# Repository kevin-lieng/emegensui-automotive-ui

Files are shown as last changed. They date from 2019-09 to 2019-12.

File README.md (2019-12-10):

# 2019 - 2020 AutomotiveUI (IMU Sensor)
## BerryIMU + ESP8266 Build Instructions

## System Diagram

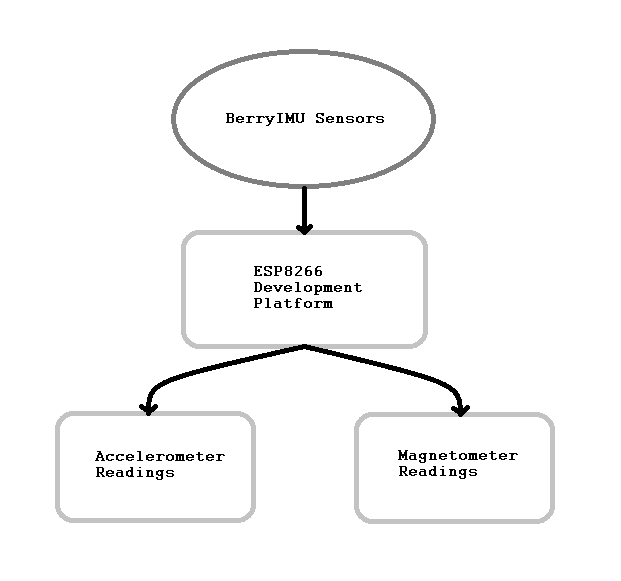
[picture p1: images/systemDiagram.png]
systemDiagram


Using the system diagram above, you can visualize how the BerryIMU interacts with the ESP8266 Development platform to retrieve the readings of the sensors within it. Although there are only two sensors that are being read within the above diagram, there are still several more sensors that can be used to retrieve data. 

## Introduction
--------------------------------------------------------
BerryIMU is a third-party made PCB board that has several sensors that can be used to retrieve data. IMU stands for Inertial Measurement Unit, these are the units that relate to the movement of something. Not only is this third-party sensor capable of reading movement, but it can also read temperature, pressure, and geographical location. However, this documentation will be discussing the 
usage of this sensor to retrieve the data of basic movement and direction. Within this repository, you will find the multiple files that are available to use alongside with the instructions given for public use. These files can aid in the installation of the hardware and the software needed for the basic functionality of retrieving intertial and directional data. 

## Table of Contents 
--------------------------------------------------------
- [System Diagram](#System-Diagram)
- [Introduction](#Introduction)
- [Components Needed (Cost)](#Components-Needed-Cost)
- [Time Commitment](#time-commitment)
- [Mechanical Assembly](#mechanical-assembly)
- [PCB and Soldering](#PCB-and-soldering)
- [Enclosure](#Enclosure)

--------------------------------------------------------

## Components Needed (Cost)
-------------------------------------------------------
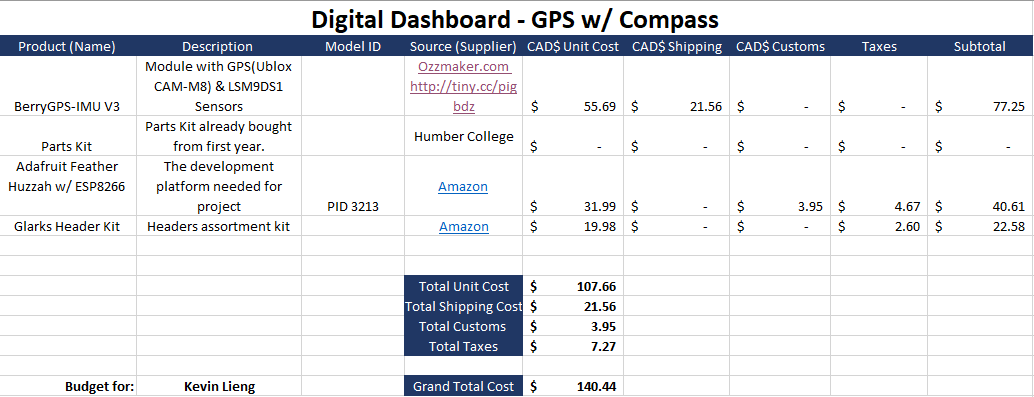
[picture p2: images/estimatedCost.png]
estimatedCost

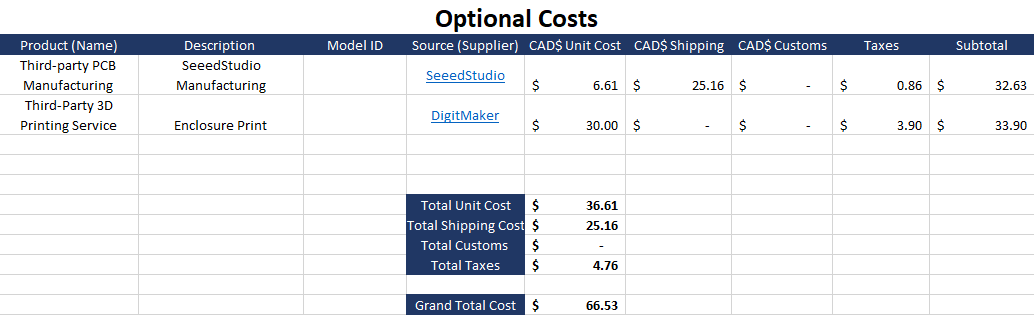
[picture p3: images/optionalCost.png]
optionalCost


The cost of the product depends on what type of services are available to you as a student or individual. If there are services near you that offer fine 3D printing services and fine PCB services at no cost, you may ignore the optional costs of this project. The necessary components of this project are stated within the first image of this section. Due to the main sensor, BerryIMU, being made by a third-party in Australia. The shipping of this component may take longer than the others listed. Most of these components may ship to you at no cost due to the availability of them on Amazon. 

The minimum cost of the project can be $140.44; however, if third-party manufacturing and printing services are needed, the upper cost can be $206.97.

## Time Commitment
-------------------------------------------------------
By using this documentation, a user can potentially finish this project within a day to three days depending on the avaialbility of the components needed within this project. 

On completion of this project, the final product should look like the following pictures below: 

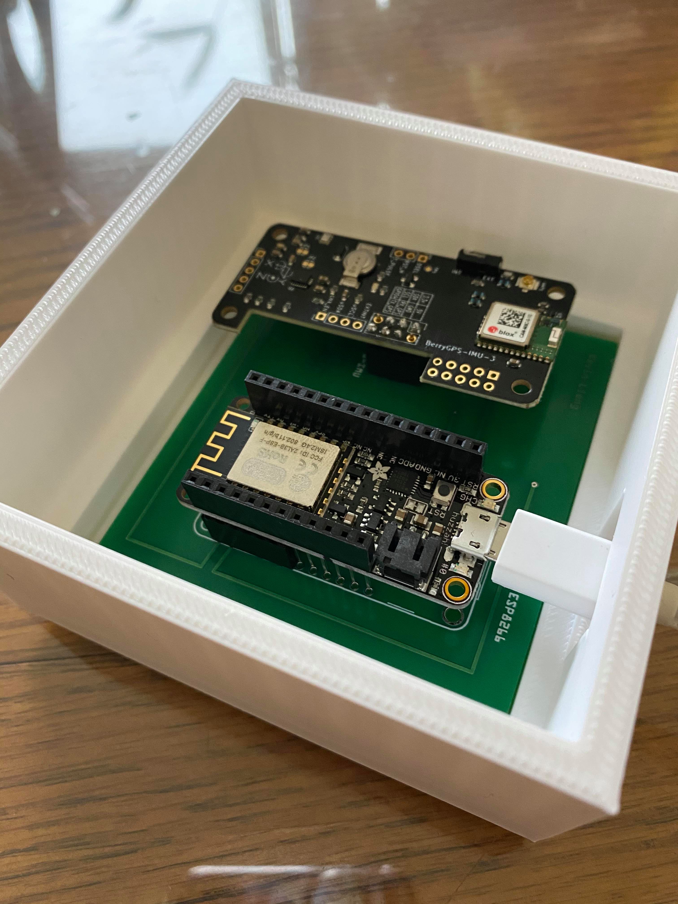
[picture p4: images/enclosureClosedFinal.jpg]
FinishedProduct

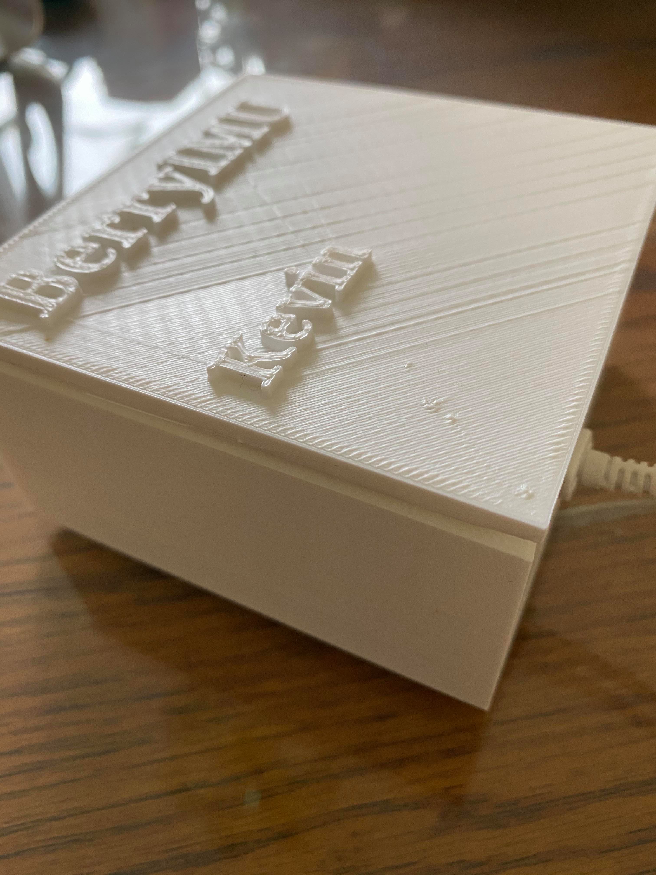
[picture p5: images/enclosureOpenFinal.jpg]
FinishedProductOpen


Although a user using this documentation can develop the project in three days with this documentation. The planning of this project took a span of 3 months to plan out the implementation of the PCB board, enclosure, and multiple testing as seen below. 

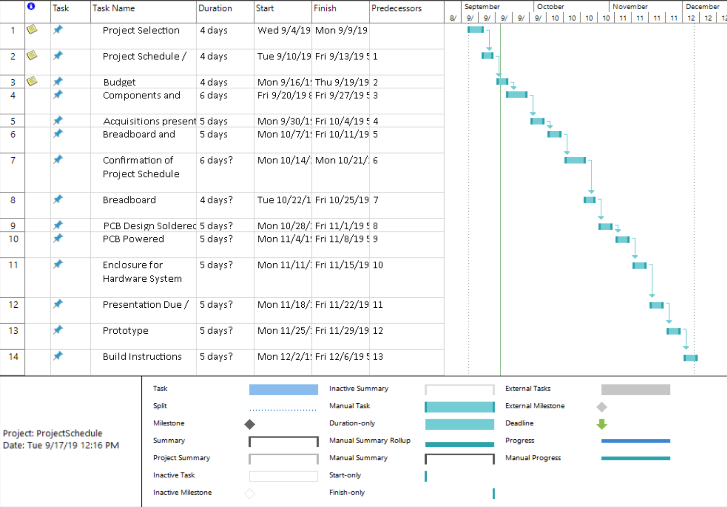
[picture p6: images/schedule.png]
SchedulePDF


This is due to the extra time needed to work out errors that have occured and the switching of development platforms and remaking of PCB board and enclosures to meet the new components needed. The components that are shown as needed in the [budget](#components-needed-cost) portion above have the unnecessary products taken out. If you would like to see the the previous components that were used, the may be found [here](documentation/ProjectBudget.pdf).

## Mechanical Assembly
------------------------------------------------------------
### Step One : Setting up the Adafruit Feather Huzzah ESP8266

Before connecting the sensor to the development platform, ESP8266, you should setup the development platform itself. The development platform should be enabled to be programmed through the Arduino IDE (Integrated Development Environment). 

To start, you would need to [download the Arduino IDE from Arduino.cc](https://www.arduino.cc/en/Main/Software).

Next, you would have to integrate the board drivers of the ESP8266 into the Arduino IDE by copying the following:

    http://arduino.esp8266.com/stable/package_esp8266com_index.json

This link should be copied and pasted into the Additional Boards Manager URL field. This field can be found under **File > Preferences** . The window for this section should look like the following: 

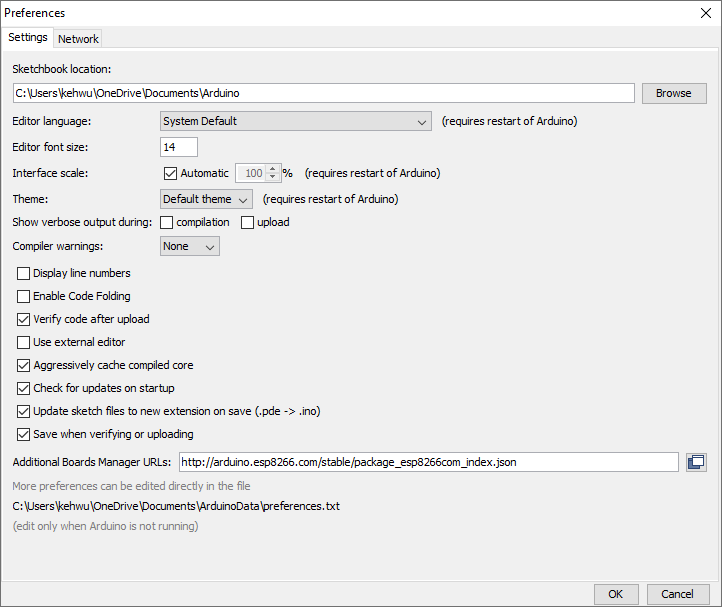
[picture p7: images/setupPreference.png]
preferences


Next, you will have to navigate to the board manager through the top menu using: **Tools > Boards > Board Manager** . You will then have to install the ESP8266 board drivers and made by the Arduino Community. The screen of the board manager will appear as this in Windows: 

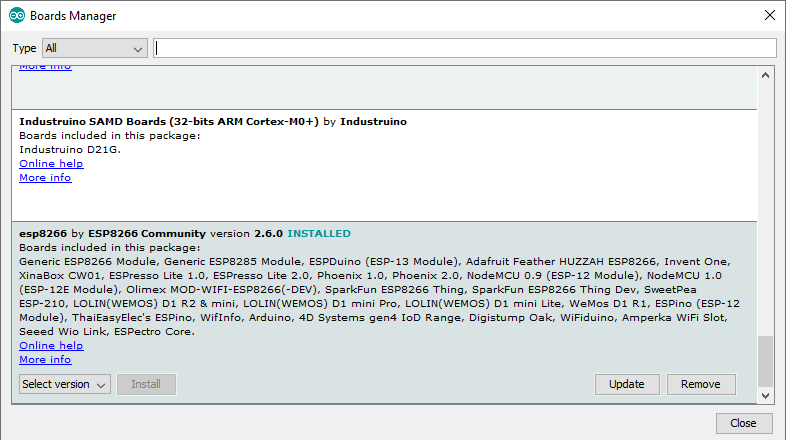
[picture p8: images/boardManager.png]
boardManager


After the installation, you may connect the ESP8266 development platform to your computer / laptop using a MicroUSB to USB cable to a USB Port of your device. After connecting, you will have to select the correct port of your ESP8266 platform. This is done through the top menu using **Tools > Port > COM#**, you will have to select the correct COM port of your device. 

After the sucessful connection of your platform, you will then need to test your platform by running a simple **Blink Test** by using the following code:

    void setup() {
    pinMode(0, OUTPUT);
    }
 
    void loop() {
    digitalWrite(0, HIGH);
    delay(500);
    digitalWrite(0, LOW);
    delay(500);
    }

Upon the successful uploading of this code to your platform, you shall see the LEDs of the ESP8266 to be blinking. 

### Step Two: Connection of the BerryIMU Sensor

The next step would be the connection of the BerryIMU sensor to the development platform itself. The best way to do this would be to first solder male headers to the sensor itself. In the following locations:

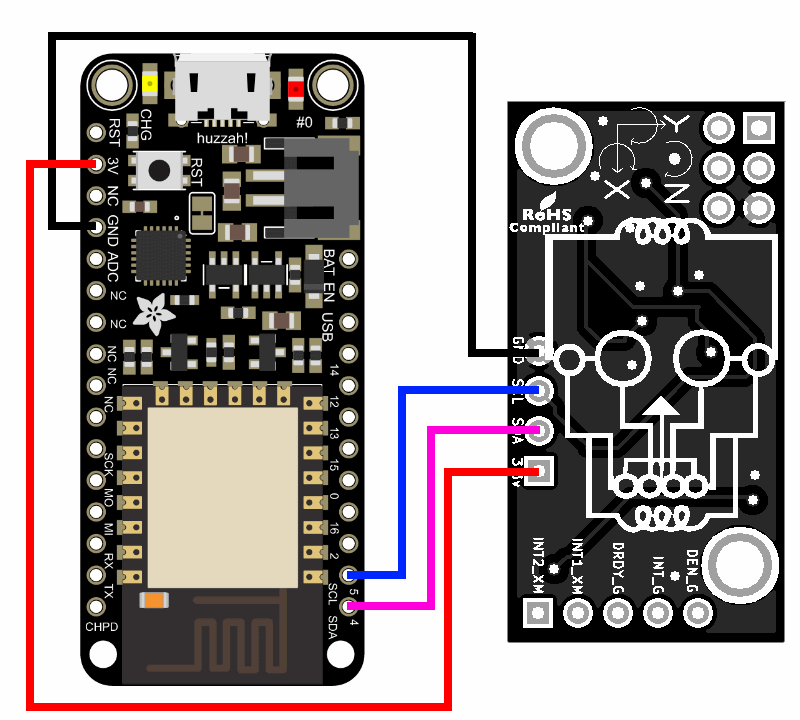
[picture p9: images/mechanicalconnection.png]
mechanicalConnection


After soldering male headers to those pinouts of BerryIMU sensor on the right, you can then use several female to female wires to connect the sensor to the platform like the diagram above. 

## Step Three: Implementing Code For Testing

The next step would be to implement the code for testing the sensors itself and if they're capable of reading gyrometer, magnetometer, and accelerometer data. To do this, you can start a new sketch within the Arduino IDE and have the main file include the code within the BerryIMU.ino file. 

- [BerryIMU.ino File](software/BerryIMU%20Codes/BerryIMU.ino) 

You can then include the following files within the same folder of the main BerryIMU.ino file: 

- [IMU.cpp File](software/BerryIMU%20Codes/IMU.cpp)
- [IMU.h File](software/BerryIMU%20Codes/IMU.h)
- [LSM9DS0.h File](software/BerryIMU%20Codes/LSM9DS0.h)
- [LSM9DS1.h File](software/BerryIMU%20Codes/LSM9DS1.h)

When implemented correctly, your Arduino IDE window should look like the following: 

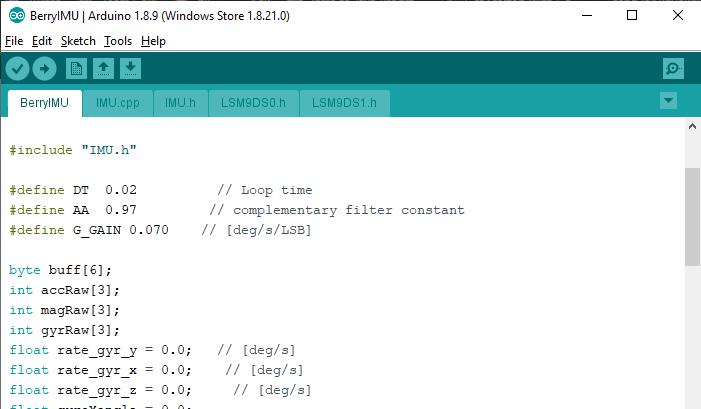
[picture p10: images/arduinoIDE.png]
arduinoIDE


### Step Four: Uploading and Checking Readings

After the implementation, you may now upload the program into the ESP8266 development platform. After the successful upload of the program, you can open the Serial Monitor within the Arduino IDE to see the readings of the sensor. To test for movement, you may move the sensor around and check for movement in the readings. 

The Serial Monitor can be found in the same top menu of Arduino IDE under **Tools > Serial Monitor**. When the correct window is open, the screen will look like the following: 

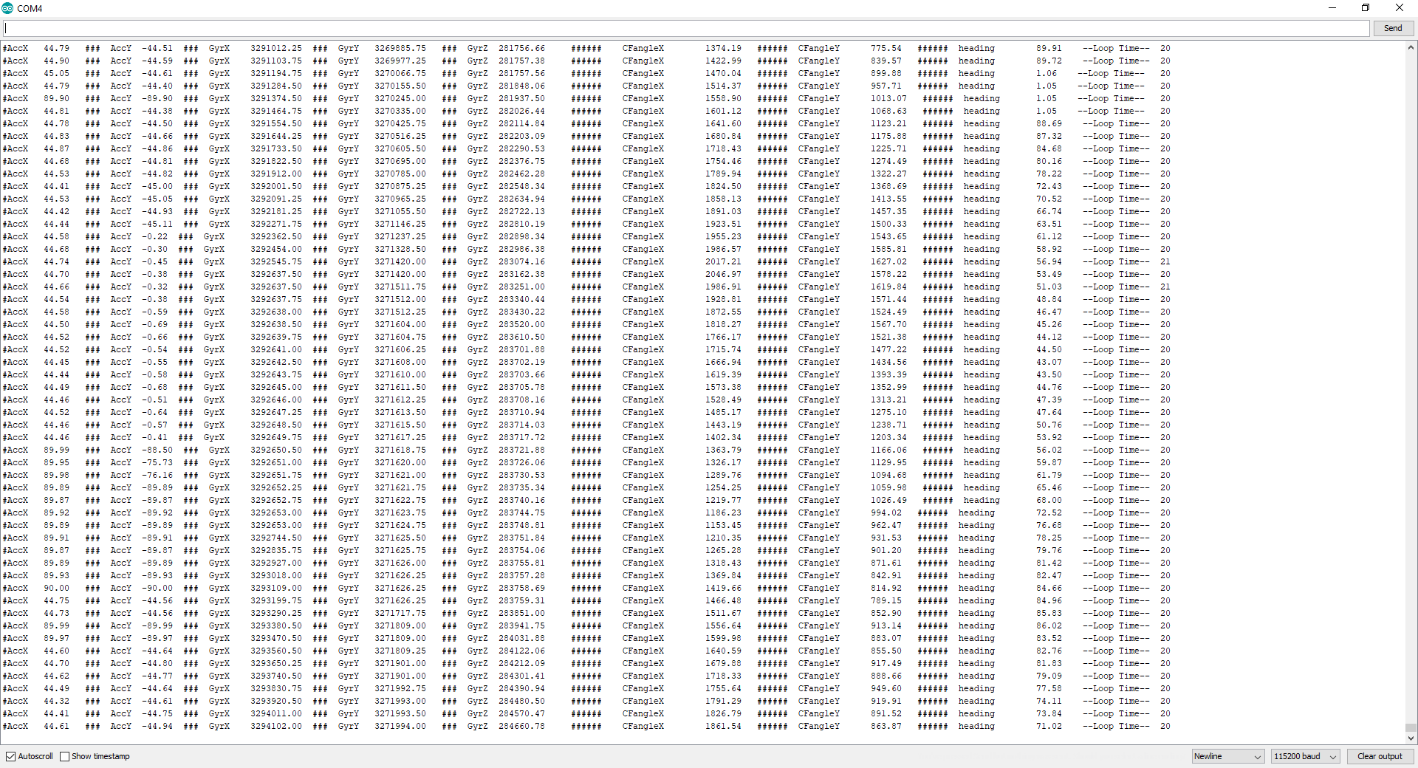
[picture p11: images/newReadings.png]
newReadings


When you have achieved the window above, you are halfway complete the project and ready for the soldering of the PCB and creation of the enclosure. 

## PCB and Soldering
-------------------------------------------------------
The creation and implementation of the PCB is to remove the wires needed to have the hardware function. To simplify this step, I have included the gerber files inside of a RAR file that can be found here: 

- [PCB Gerber Files](electronics/PCB%20Gerber.rar)

The file above can be sent to a PCB manufacturing service to retrieve a PCB for soldering. When the PCB is done and retrieved, you may solder the following pinouts with female headers: 

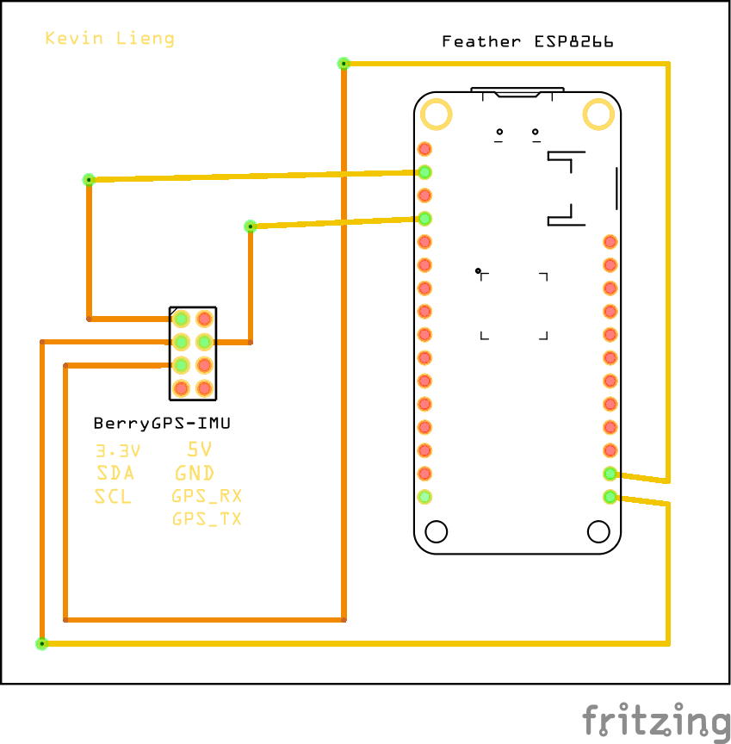
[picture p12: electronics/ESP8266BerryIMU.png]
newPCB


After the soldering of female headers onto the above pinouts, you can solder male headers onto the 3.3V, SDA, SCL, and GND pinouts of sensor and development platform. Feel free to solder more than needed if it would make it easier to hold the sensor and ESP8266 onto the PCB. After soldering, the sensor, ESP8266, and PCB can be connected like the following:

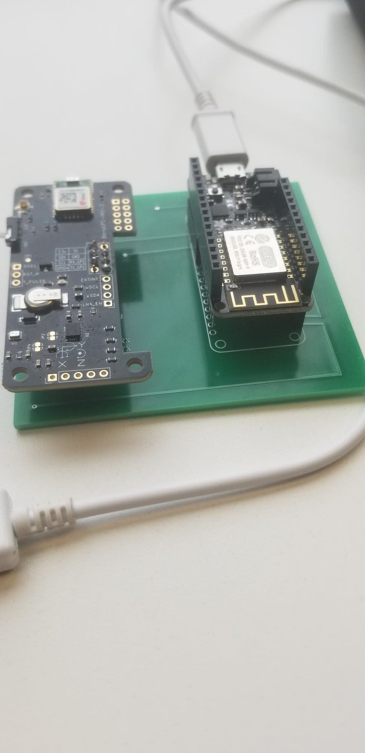
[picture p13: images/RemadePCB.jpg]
PCBConnection


After the connection of the PCB, sensor, and ESP8266, you may reconnect the hardware to your computer to test if the program still works. The readings of the program should still be the same as the first testing. 

## Enclosure 
------------------------------------------------------------
The final portion of this project can be done by using the stl files found in this repository. These files contain the design of the enclosure of the project and can be used to slice and 3D printed through school or a third-party printing service. The files can be found here:

- [Enclosure](mechanical/PCBEnclosureFixed.stl)
- [Enclosure Lid](mechanical/PCBEnclosureLidFixed.stl)

By using Cura, you may use these files to slice them and retrieve a **.g file** . This **.g file** are used by 3D Printers for printing purposes. When using a third-party 3D printing service however, you only require the stl files. They would slice the project itself and print the enclosure for you. 

When the enclosure is received, there will be hole at the back of the enclosure to allow for the MicroUSB to pass and connect to the development platform of ESP8266. There is no need for ventilation at this version of the project due to the sensor only reading and measuring inertial and directional values. 

After the integration of the enclosure and the project, the final product looks like the following: 

FinishedProduct
FinishedProductOpen

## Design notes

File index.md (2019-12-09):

# EmergensUI Blog

#### Blog Entry #17 (December 8, 2019)
The build instructions have now been included within the README.md file within the repository.
Please feel free to [click the following link](https://github.com/kevin-lieng/emegensui-automotive-ui/). 

The link above will include the readme file at the bottom, available for reading. 

#### Blog Entry #16 (November 25, 2019)
The presentation for my hardware project has been completed and will be uploaded for viewing on my GitHub account following this blog post. Currently on schedule and ready to present November 26, 2019 at 2:15PM. 

Presentation can be found here:

[Presentation](https://github.com/kevin-lieng/emegensui-automotive-ui/blob/master/documentation/HardwareProjectPresentation.pptx)

#### Blog Entry #15 (November 21, 2019)
I received the PCB from the third-party source and the dimensions of the enclosure fit my PCB with its sensors and development platform. The enclosure is also able to close; however, the closure doesn't lock in place and is loose. This is fine, since the movements of the sensor should be as minimal as possible to achieve proper readings of changes. 

The enclosure pictures can be found in the portion below this blog post:
closedCase
openCase

#### Blog Entry #14 (November 18, 2019)

On this date, I received the new PCB that I designed for my new development platform ESP8266. It was after I soldered the new PCB and tested the product that I redesigned my enclosure with new dimensions. The problem with my casing however, is that it would take too long to print at school. Therefore I have outsourced my 3D printing job out to a third-party service and a friend with a 3D printer to expedite the printing job. 

The new PCB board that I received allows the attachment of both the sensor and development platform to be attached directly to the board through female headers. 

In this blog post, I have included pictures of my new PCB and its attachments, pictures of the enclosure and the lid, and the files that are required to print the enclosure in general. 

newPCB
The new PCB with the development platform and sensor attached. 

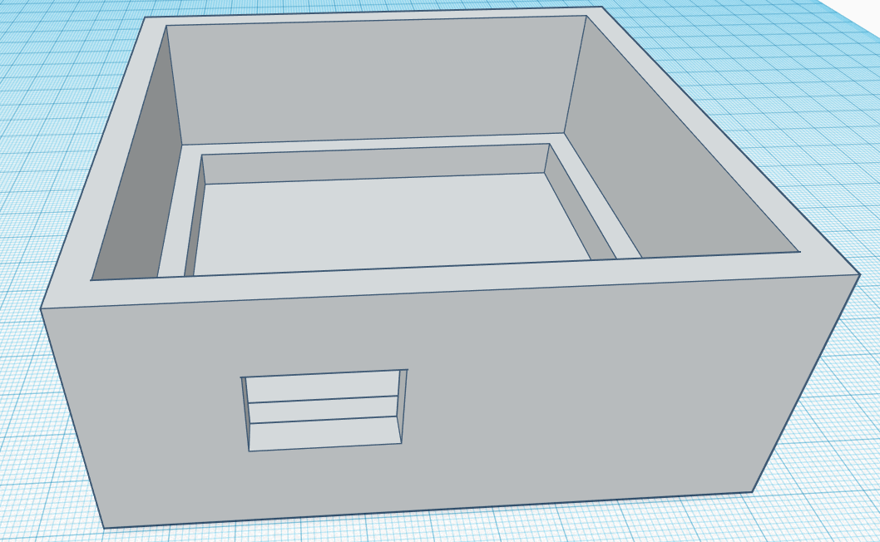
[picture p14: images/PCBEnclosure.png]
PCBEnclosure

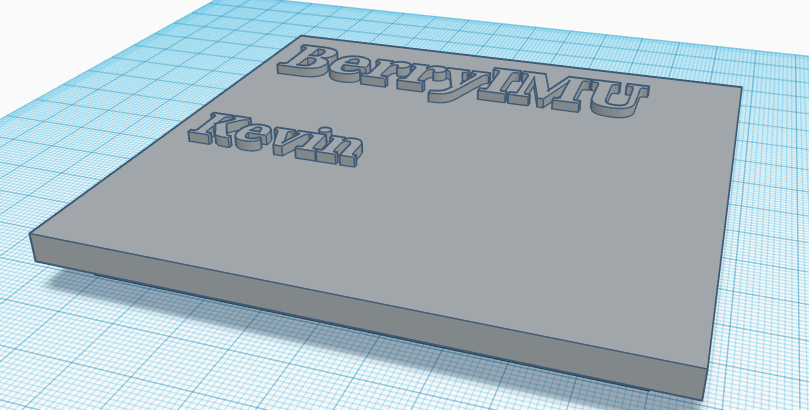
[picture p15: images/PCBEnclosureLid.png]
PCBEnclosureLid


I created this enclosure through the use of an online CAD program called TinkerCAD and exported the STL files included below: 

[PCBEnclosure](https://github.com/kevin-lieng/emegensui-automotive-ui/blob/master/mechanical/PCBEnclosureFixed.stl)

[PCBEnclosureLid](https://github.com/kevin-lieng/emegensui-automotive-ui/blob/master/mechanical/PCBEnclosureLidFixed.stl)

#### Blog Entry #13 (November 12, 2019)

Achieved results with my testing today with the new development platform (Adafruit Feather Huzzah! ESP8266), it proved that the PCB board was not the problem but my previous development platform the STM32 blue pill. When connecting the sensor and development platform to the customized PCB, I was able to retrieve results. 

These results can be shown in the pictures below. However the new PCB board that I have designed will have both of them fitting onto one board. The new design will also be posted below. 

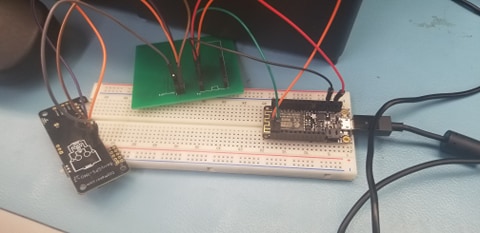
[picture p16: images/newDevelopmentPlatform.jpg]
newConnection

newReadings
newPCB

Due to this issue, I am behind schedule by a week, but I can catch up using dimensions of the new PCB board, sensor, and development platform. 

#### Blog Entry #12 (November 12, 2019)
Although my PCB was capable of turning on, it wasn't possible for it grab readings due to the previous errors. I have ordered my new IDE and PCB with redid fritzing for a new PCB part. Due to this error, my financial budget went over the said amount that was stated in the previous parts. With the retrieval of my new part, I was able to read the sensor through testing constantly because of this constant reading that I'm able to get, I have ordered a PCB board along to go along with the new IDE. 

The new fzz file for the schematic of my build can be found here. 

[Huzzah! + Sensor Fzz](https://github.com/kevin-lieng/emegensui-automotive-ui/blob/master/electronics/Feather%20%2BBerryIMU%20%20Remake%20PCB.fzz)
#### Blog Entry #11 (November 7, 2019)
After thorough testing my soldered PCB, I finally discovered the reason why my sensor had not been working with my Blue Pill, the voltage that it's been sending out to the sensor wasn't strong enough to turn on the sensor in the first place, but it still ran the program without reading anything, such as seen in the prior posts. 

Further evidence can be seen here in the image below. 

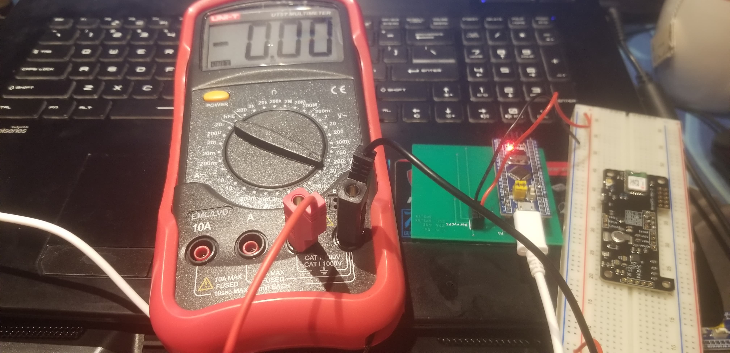
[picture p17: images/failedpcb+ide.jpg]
FailedPCB


According to the above picture, you can see that the portions where it should be giving out 3.3V isn't doing so. Even when the voltmeter is attached directly on both 3.3V and GND, it cannot read 3.3V . Therefore, I have decided to switch IDEs completely, but still working on arduino type coding. The next IDE I've decided to tryout is the Adafruit Feather Huzzah! ESP8266 that also works through ArduinoIDE code. 

#### Blog Entry #10 (October 29, 2019)

Demonstrated my breadboarded demo to Professor Kristian Medri; however, it seemed to not be reading correctly. SDA and SCL data transmission didn't seem to work correctly between the Arduino and my sensor. There may have to be a change in IDE or Development platform. However, gotta first recheck the addresses on the sensors to see where the SDA and SCL are reading from. 

Pictures of the breadboarded demo can be found below.
Codes can also be found in the current folder on github.

[Codes](https://github.com/kevin-lieng/emegensui-automotive-ui/tree/master/software/BerryIMU%20Codes)

Breadboarded Arduino + Sensor Design + Readings

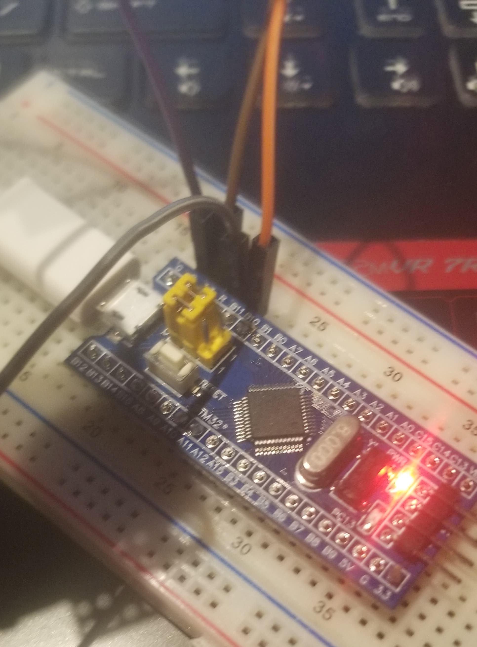
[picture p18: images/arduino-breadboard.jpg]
BreadboardDemo

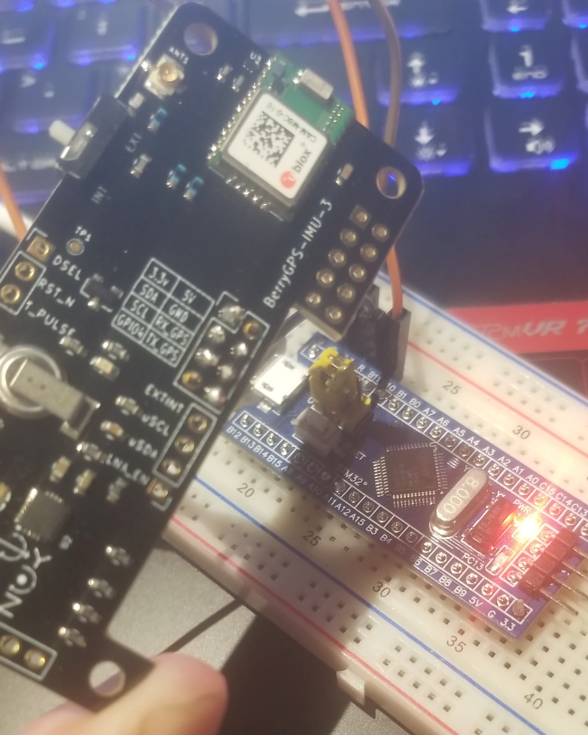
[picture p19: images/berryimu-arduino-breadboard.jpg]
SensorConnection

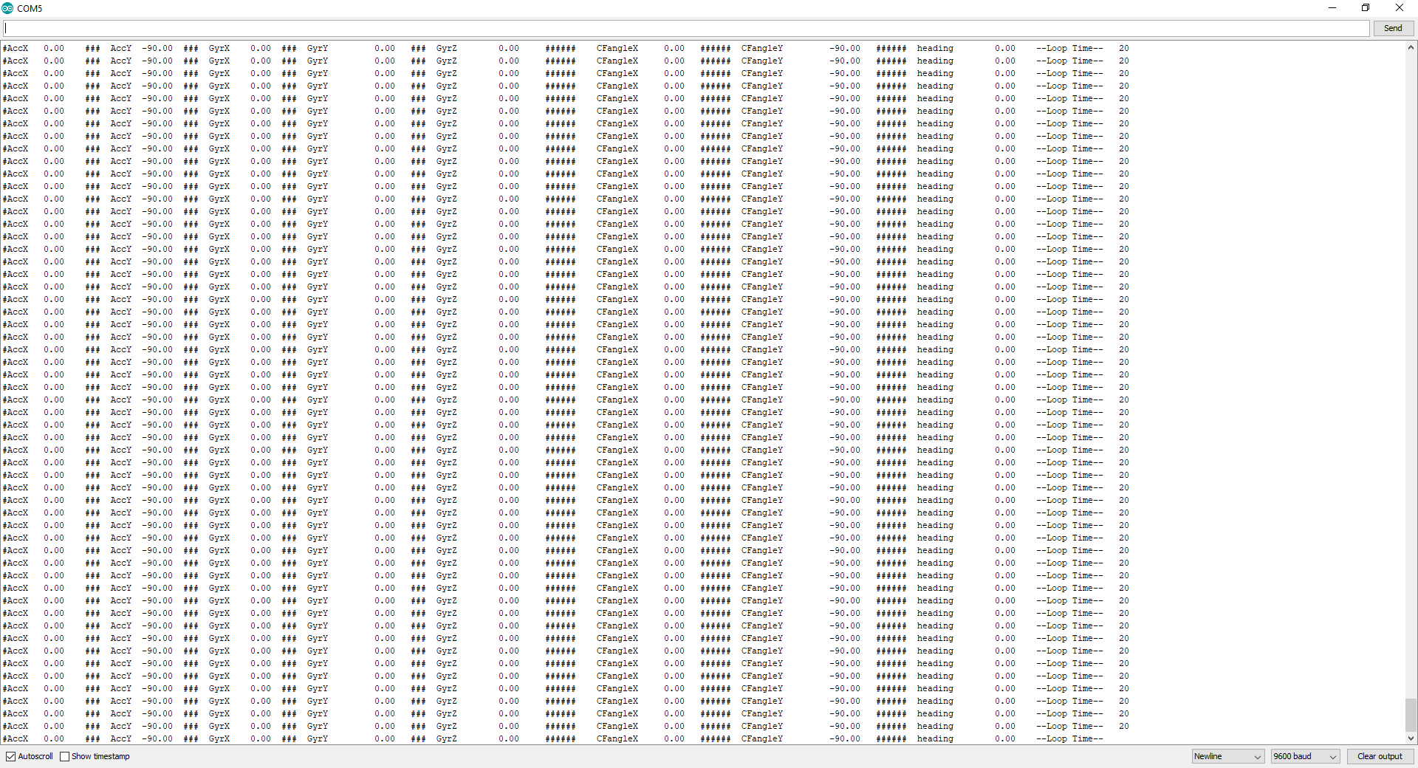
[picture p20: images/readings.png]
Readings


#### Blog Entry #9 (October 15, 2019)

Created the PCB board for the project, uploaded the schematics, breadboard design, and pcb design. I made some mistakes, during my PCB arrangement but received 
help from Professor Kristian Medri. I have made the corrections and reuploaded revised versions of each below section of my PCB and Breadboard design below.

[Schematics](https://github.com/kevin-lieng/emegensui-automotive-ui/blob/master/electronics/PCB%20Schematic.png)

[Breadboard Design](https://github.com/kevin-lieng/emegensui-automotive-ui/blob/master/electronics/PCB%20Breadboard%20Design.png)

[PCB](https://github.com/kevin-lieng/emegensui-automotive-ui/blob/master/electronics/PCB%20Board%20Plan%20-%20Revised.png)

[Fizz File](https://github.com/kevin-lieng/emegensui-automotive-ui/blob/master/electronics/NoSTM32.fzz)

Images can also be viewed below this post. 

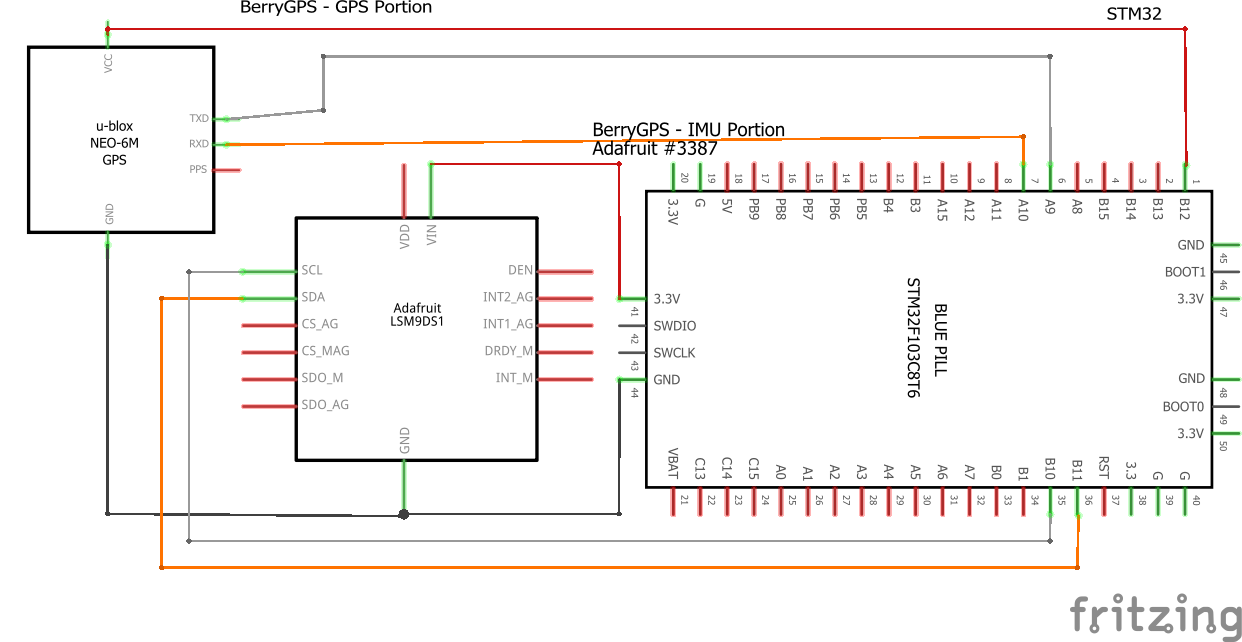
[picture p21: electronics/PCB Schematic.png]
Schematics

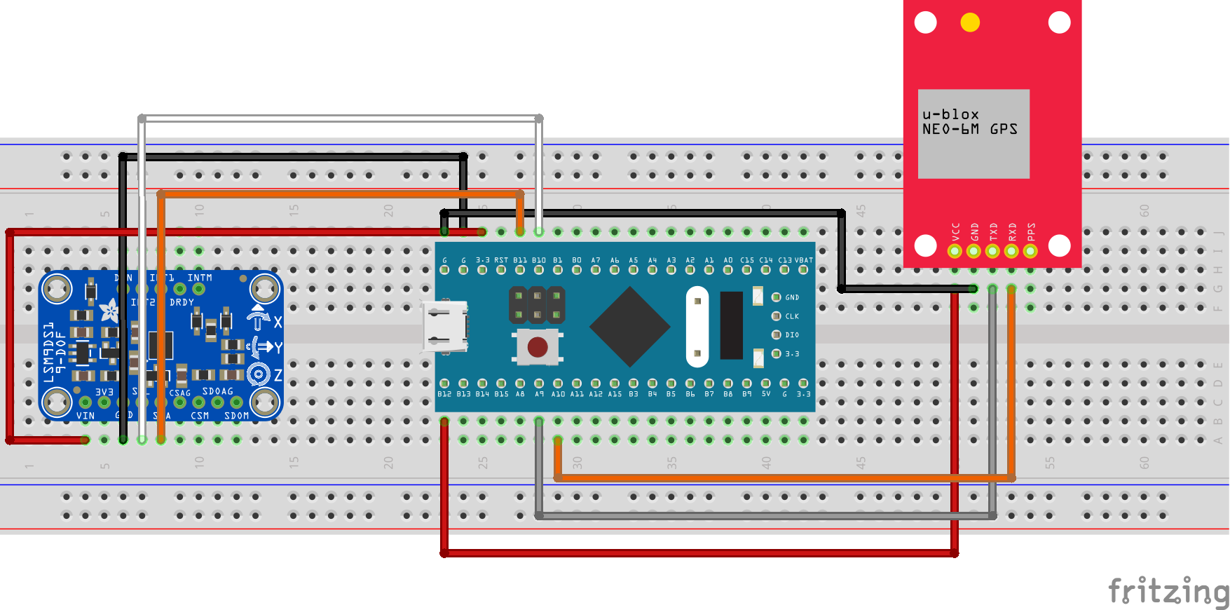
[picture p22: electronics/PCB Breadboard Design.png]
Breadboard Design

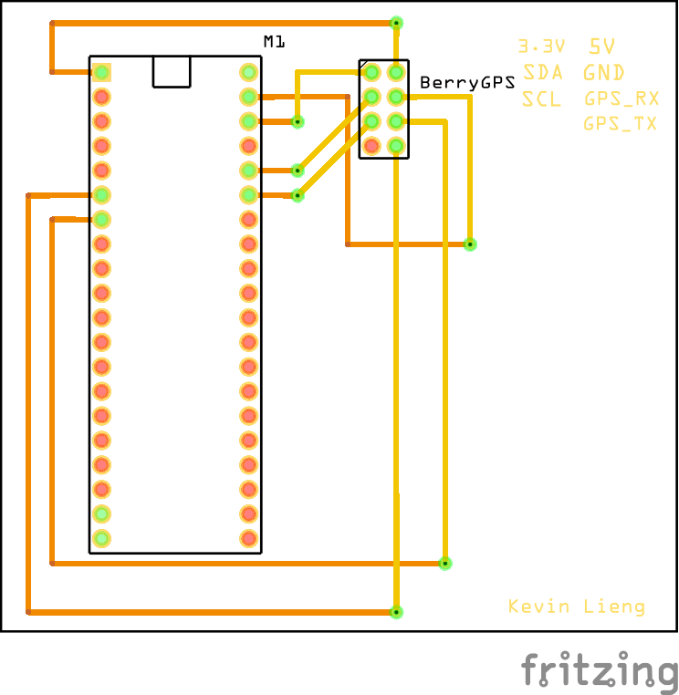
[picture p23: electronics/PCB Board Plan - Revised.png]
PCB


We have also met with our colloborator Professor Dennis Kappen after our PCB check up. We have received some feedback and what he believes will help us during our future
software and hardware plans for the rest of the system.

#### Blog Entry #8 (October 8, 2019)

Confirmed purchases with the rest of the group, retrieving headers for the connections of Blue Pill and Sensors.

#### Blog Entry #7 (October 1, 2019)

Orders for the items included in the budget have been placed. Proof of purchases of those orders have been uploaded to github to be made for viewing. 

Links for the document have been included below.

[Proof of Purchases](https://github.com/kevin-lieng/emegensui-automotive-ui/blob/master/documentation/ProofOfPurchases.pdf)

#### Blog Entry #6 (September 24, 2019)

Previously discussed the budget with the group of EmergensUI and the different sensors that we're all going to use, made sure that each of our sensors correspond to our proposal properly. 

Current budget for my portion can be found here. 

[Budget Excel Sheet](https://github.com/kevin-lieng/emegensui-automotive-ui/blob/master/documentation/ProjectBudget.xlsx)

[Budget PDF](https://github.com/kevin-lieng/emegensui-automotive-ui/blob/master/documentation/ProjectBudget.pdf)

#### Blog Entry #5 (September 18, 2019)

Rediscussed the software project with Professor Austin Tian, confirmed that we're working on HUD2 (Driver Assist) and trying to improve the pre-existing one. Got verification from Austin Tian that our idea in including a medical information tab within the vehicle dashboard. 

#### Blog Entry #4 (September 17, 2019)

Discussed the project schedule with the group members and included several project notes to serveral tasks to indicate that they have been completed. Will update schedule as more tasks are completed.

Uploaded and handed in project schedule to Professor Kristian Medri. 
Uploaded copy can be found on GitHub. 

Click [here for schedule pdf](https://github.com/kevin-lieng/emegensui-automotive-ui/blob/master/documentation/AutomotiveUIProjectSchedule_SGanttChart.pdf).

#### Blog Entry #3 (September 10, 2019)
Uploaded and handed in the proposal of the hardware section of the EmergensUI to GitHub and to Professor Kristian Medri. 

Click [here for proposal](https://github.com/kevin-lieng/emegensui-automotive-ui/blob/master/documentation/ProposalContentStudentNameRev03.pdf). 

Also met up with Professor Dennis Kappen today for a further explanation of the specific scenario of the Vehicle Digital Dashboard. Discovered there were two separate versions of this. 

HUD1 - The augmented digital dashboard for augmented video/audio information for the partner within the Ambulance. Relays audio/video messages from the dispatcher to display augmented scenario and help within the HUD or this section of the dashboard.

HUD2 - The driver assist of the digital dashboard. Relays GPS and vehicle information to the driver to aid the driver en-route to the patient and back to the hospital. 

We've decided to work and try to improve the HUD2 portion of the digital dashboard and include some medical information for the driver to access and view to make good speed estimates when driving.

#### Blog Entry #2 (September 09, 2019)
After much discussion amongst the group members and retrieving more details of the project from Professor Austian Tian and Professor Kristian Medri throughout the weekend. The group has discussed the different sensors that we are capable of doing to recreate a digital dashboard that may be in working condition. After our many decisions we were all able to finish our proposal and push the changes onto our own repositories. 

#### Blog Entry #1 (September 05, 2019)

It was on this date that we joined up as a group and chose the automotive UI and digital dashboard. After making collaborating together, we each created our own repository.

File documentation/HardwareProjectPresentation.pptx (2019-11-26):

## BerryIMU – ESP8266

Accelerometer, Gyrometer, Magnetometer

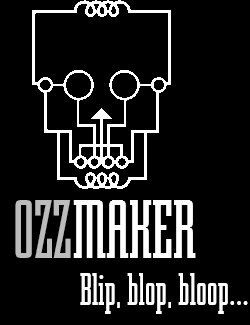
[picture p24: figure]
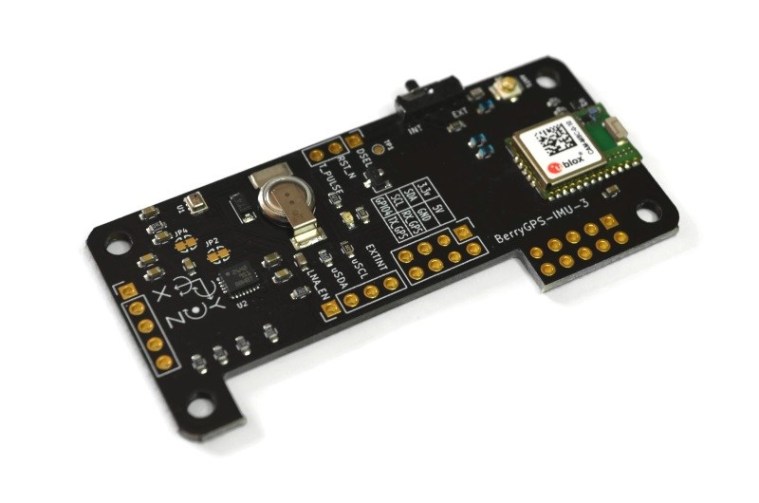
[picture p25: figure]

Kevin Lieng
https://kevin-lieng.github.io/emegensui-automotive-ui/

## Proposal

- The main project: Automotive-UI (Digital Dashboard)
  - Design of the main project is meant for paramedics and future ambulances
  - Hardware: (Gyrometer, Accelerometer, Magnetometer)
    - Would assist the main features of a regular dashboard of a vehicle
    - Keep the vehicle’s direction tracked for future GPS purposes
  - Our goal is to decrease the amount of time needed for information to transfer between dispatcher and paramedics

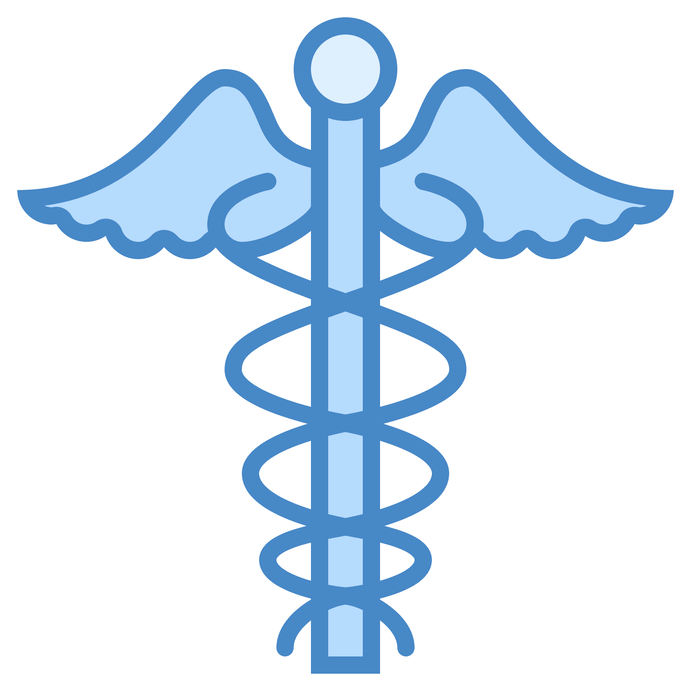
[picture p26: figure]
Staff of Hermes Medicine Rod of Asclepius Health Clip art - golden medical symbol png download - 1600*1600 - Free Transparent Staff Of Hermes png Download.

## Budget

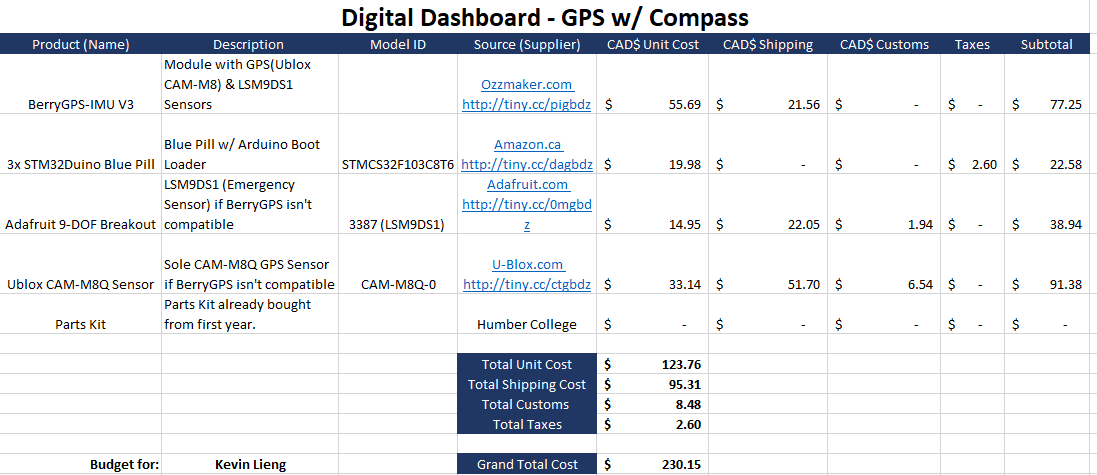
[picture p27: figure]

- The original budget ended up being lower due to the not having to purchase the bottom two parts
  - However, with the addition of outsourcing my PCB and enclosure to a third-party manufacturer, changing my development platform to ESP8266
    - PCB : $4.90 USD + 21.99 USD shipping Enclosure: $35 CAD + 0 shipping ESP8266: $31.99 CAD + $4.16 Tax Headers: $19.98 CAD + $2.60 ( Group Use )
    - New Grand Total: $223.56

## Schedule

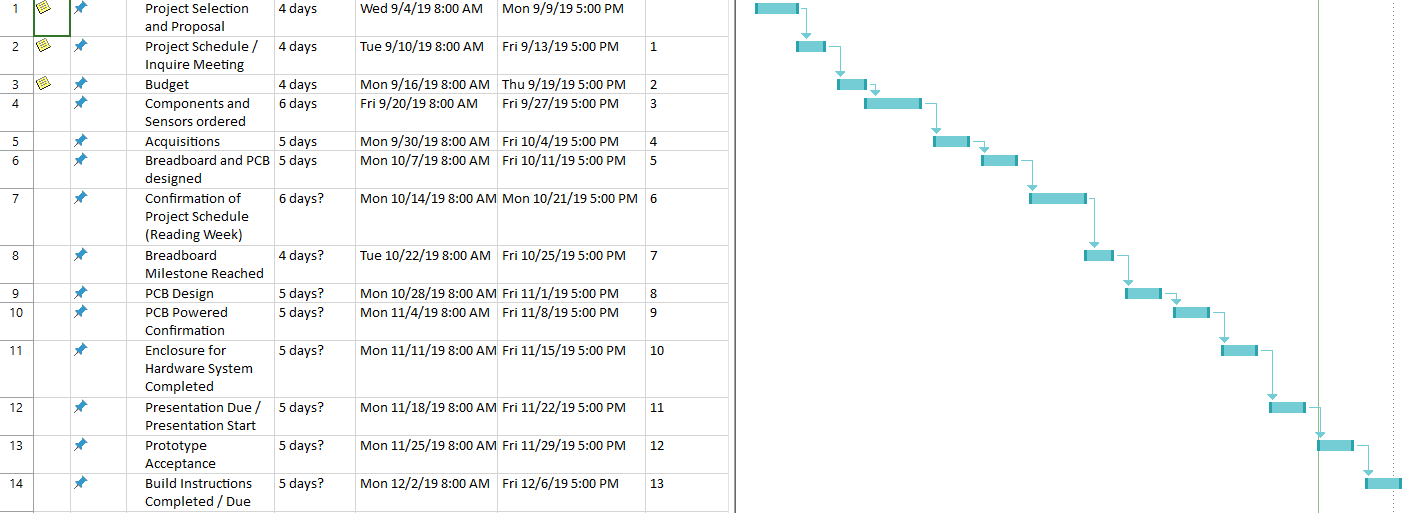
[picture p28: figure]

- There were several points in time, where I fell behind schedule
  - Week 10 & 11 when during the PCB power up and enclosure due dates
    - STM32 Blue Pill (faulty) wasn’t able to send 3.3V nor read from the sensors
    - Had to replace with ESP8266 another Arduino-like development platform, redesign the PCB, get the PCB remade and remake the enclosure accordingly
    - Received the new PCB, soldered, powered up, checked readings all on the week to design enclosure

## Images


## Images (cont’d)


## Course Knowledge

- TECH101(Electric Circuits) & TECH103 (Digital Fundamentals):
  - Learning to create different circuits and to take measurements
- TECH150 (Electronic Devices & Circuits):
  - Learning to solder through power supply project
- CENG216 (Intro to Software Engineering):
  - Learning how to create schedules and the understanding of Gantt charts

QUICK DEMO

## References

- OzzMaker. (2014). [Ozzmaker Logo]. Retrieved from https://i1.wp.com/ozzmaker.com/wp-content/uploads/2014/06/OzzMaker-Skull-250-side-bar-negative.png?w=250

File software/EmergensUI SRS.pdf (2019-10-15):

# Software Requirements Specification

## for

# EmergensUI – Automotive UI

Version 1.0 approved

Prepared by Kevin Lieng, Quyen Lu, Seung Min Song

Humber College

September 30, 2019

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
Introduction

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
4 Intended Audience and Reading Suggestions | 4 References | 4

Overall Description

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
d Im

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
External Interface Requirements

7
U

s

e

r In

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
e In

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
s In

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
System Features

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
tific

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
4.1.1 Description and Priority

8
4.1.2 Stimulus/Response Sequences

8
4.1.3 Functional Requirements

8
Other features (TBD)

9

Other Nonfunctional Requirements

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
alit

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
Other Requirements | 10

## Revision History

Name | Date | Reason For Changes | Version
EmergensUI | Oct 4, 19 | First documentation released. | 1.0

## 1. Introduction

### 1.1 Purpose

The purpose of this documentation is to provide further information about our product, EmergensUI, an Automotive UI based on the android platform. This document will go into depth of usage, benefits, features, security and other requirements of the software. This document is to be maintained and updated as further progress of the software is made or changed.

### 1.2 Product Scope

The software portion of EmergensUI will be utilized by employees of emergency medical services that aims to improve their communication and decrease the time wasted during medical emergencies. The software will be designed to help employees:
Decrease the time required to communicate between each other
Prepare for specified medical emergencies
Access a secure database containing sensitive information
View sensitive patient medical information
Transfer sensitive patient medical information

### 1.3 Intended Audience and Reading Suggestions

This document will be utilized by the internal IT management of different hospital locations that have purchased a license and maintaining their database of patients and employees. This documentation of EmergensUI provides thorough specifications of the software including software requirements and functionality. It will provide information through a broad description of the software, explain the target audience, several software features and the requirements of the application as a whole. It is recommended for the reader of this document to grasp the concept of the software before reading forward into the features and requirements. Specific information such as conceptual software information can be found in section 2, individual software features are explained in section 4, and software requirements can be found in section 5 in this document.

### 1.4 References

References will be supplied if needed during future revisions.

## 2. Overall Description

The software, EmergensUI, an android based application was created to ease the communication and transfer of medical information of patients to specialists and hospitals to prepare for any scenario. The system will be able to provide certain employees with specific patient information according to their specialization. This application will be used alongside an online database server throughout the whole system to provide its services.

### 2.1 Product Perspective

EmergensUI is an application that allows the communication between medical professionals and paramedics, transfer of patient information, GPS information for specific scenarios. All information on patients will be kept on a secure online database which requires medical staff to log in. The GPS functionality will be available upon detection of a medical service vehicle.

### 2.2 Product Functions

The main functions of EmergensUI consists of: ❖ Verification
❖ Authorization
❖ Encryption
❖ Communication
❖ Data Transmission
❖ GPS Navigation

On start of application, verification takes place whether through account login or bluetooth connection to a medical service vehicle. This step gives authorization to specific users to access certain information such as decrypted sensitive information or GPS navigation. The application allows logged in users to communicate with one another to share data. A non-user can still access the application; however, most features are hidden until logged in. On detection of a non-user, application should still be able to function as a navigational tool.

### 2.3 User Classes and Characteristics

Access within the EmergensUI application changes upon login and gives authorization to certain information. The authorization differentiates these users into different classes and gives them access privileges according to their class. The users of this application are known to be different employees within emergency medical services; thus, within the application we have split the access levels according to the same titles within the field. The user classes that currently exist within the app are, non-users, paramedics, nurses, and doctors. Where non-users have the least access to features, whereas doctors have the most access. The main objective of the application is to create an environment that eases the communication between the users, such as those in the medical field. Thus, in terms of satisfaction, we aim to please those that are within that spectrum.

### 2.4 Operating Environment

The EmergensUI is an android based application. It is designed to operate on any android device that is compatible under Android SDK version 21, widely known as Lollipop. Due to strict compatibility requirements, vehicles that are driven under Emergency Medical Services would have to implement a digital dashboard that is capable of running Android OS, specifically an operating system that is at least Lollipop or higher.

### 2.5 Design and Implementation Constraints

There are regulations implemented in the working environment in the medical industry that our application is constrained and have to abide throughout the functionality of these features. Regulations such as doctor-patient confidentiality and keeping sensitive medical history out of reach of those that should not have access is a must throughout the usage of this application. Thus, the design and implementation of the application aims to secure the sensitive information of these patients within an online database that should be able to keep information encrypted and only allow medical employees whom are users to gain access. These security protocols should be constantly kept in place to protect both doctors and patients from breaking this regulation. Our design keeps in mind the different user classes and would allow sensitive information to be transferred to one another only if required and access has been granted. The application should abide to Canadian regulations and have the ability to translate itself between English and French.

### 2.6 User Documentation

Upon the completion of this documentation, there is currently no other user documentation that is readily made available that offers tutorials on the usage of the application; however, one will be offered upon the complete release of the application. This documentation will be available on GitHub after the product has been thoroughly tested. Currently, several design templates and this SRS documentation are available within the company’s GitHub.

### 2.7 Assumptions and Dependencies

Several assumed dependencies and flaws may arise during the developmental phase of the application. In terms of dependencies, we would have to assume that our future online database is capable of holding large amounts of information and keeping them encrypted so non-users will not be able to access sensitive information. This factor can also be seen as a flaw due to the severe consequences of not being to uphold the doctor-patient confidentiality regulation. Not only will the sensitive information of patients be affected but the contact information of those within the database will be breached. The next dependency that our application will be utilizing is a third-party application or system. The navigational system that is designed by Google that is utilized by most android devices is our main dependency for our GPS feature included. We intend to use this navigational system alongside the sensors within the digital dashboard to provide a clear reading of the geographical location of the vehicle and provide a route to the nearest medical facility. Another crucial constraint is if the digital dashboard within the ambulance is not capable is running an android operating system; however, for this project we will assume that they are.

## 3. External Interface Requirements

### 3.1 User Interfaces

The application of EmergensUI will contain regular UI elements such as login textboxes, buttons and lists to help navigate through the software. There will be two different interfaces that it will main function on after the verification of the user. It will either be in Doctor/Nurse user mode or Paramedic driving user mode. These two user interfaces function similarly but different from one another.
The driver interface will provide basic vehicle information such as speed and currently location; however it will also include the current patient’s health status. By displaying such information to the driver, it will allow the driver to make better decisions when navigating through traffic. Within the interface, there is an integrated algorithm that navigates the user to the neaest hospital.
The doctor and nurse interface functions differently than the driver interface. Within this mode, it will allow the verification of the user through a login screen to allow access to further screens with sensitive information. This is used to identify and classify each user to their roles and authorize them to access certain sensitive information. This also acts as a security tool to prevent access to unauthorized users that try retrieving medical information within the database.
The screen post login, grants access to the user’s own profile interface that contains a list of patients that they have access that helps them constantly check the health status of a patient. In addition to the patient list, there will be a collaborative contact screen of the users within the current hospital facility that eases the communication between different departments.

### 3.2 Hardware Interfaces

There are three main hardware components within the digital dashboard that will enable the ambulance to communicate and transfer data to the application; however, these are features made available to paramedics. The mobile functionality will remain constant throughout most android devices owned by users within the medical industry. These three hardware components consist of a heartbeat sensor, GPS sensor and velocity sensor. These three components will be used to gather vehicle and patient information for the application to transmit back to the driver. The patient’s heart rate will be gathered by the heartbeat sensor, vehicle’s digital dashboard will gather speedometer and odometer readings from the velocity sensor, and the software will use the GPS sensor to retrieve geographical reading of the location of the vehicle. As long as the vehicle and mobile devices are running the Lollipop android operating system, it would meet the hardware requirement of the software.

### 3.3 Communications Interfaces

Data transmission is one of the crucial features of this application. Data retrieved from the sensors within the ambulance may be used to update patient information within the online database through TCP/IP protocols that allow for encryption upon sending; however, retrieving information will use the same protocol but decrypt such information. The act of encryption and decryption allow for a more secure process in keeping sensitive patient information safe

## 4. System Features

This section of the document will further explain the key features and functionality of the system as a whole. It will go through one feature per subsection and give a brief description, priority, software response, and functional requirements of each feature.

### 4.1 Emergency Notification System

### 4.1.1 Description and Priority

This feature uses sensors within the ambulance or hospital to retrieve vital information of a patient constantly. Upon a potential fatal emergency situation, the application should notify the nearest hospital or doctor of the situation. This would allow for the hospital or doctor to have a quicker reaction time to an emergency case and improve the survival rate during those scenarios. This feature will be given higher priority of 7-8 due to its capability in improving the communication of medical faculty.

### 4.1.2 Stimulus/Response Sequences

Use case scenario:

Upon the detection of a patient’s vital information through the heartbeat sensor within the ambulance, the software would create a route and send notification to the nearest hospital. This would allow for the paramedic to drive the shortest route and have the hospital prepare for the arrival of a patient during emergencies. When the software detects that the patient’s vitals are deteriorating, it would further notify the hospital and paramedic of the situation elevating to a higher level of priority.

### 4.1.3 Functional Requirements

REQ-1: Heartbeat sensor and monitoring system (application)
- Software must be capable of reading in crucial current health information of the patient and relay that into the app, this is both software and hardware requirement. Data must be precisely shown and grasped into the software.
- Software must be able to detect if connected to some sort of ambulance or paramedic device to implement this feature.
- The monitoring system must be able to detect if a patient’s vitals are dropping and send out notifications.

### 4.2 Other features (TBD)

## 5. Other Nonfunctional Requirements

### 5.1 Performance Requirements

There are specific performance requirements for the software in order to function optimally for our clients that may potentially implement this system. In order to maintain optimal usage, the sensors within the ambulance must be able to grab accurate data and transfer that data into the software at close to real time. This transfer rate must be close to within at least a second or two to retain accurate readings of the vehicle and patient. This quick transfer rate creates an environment in which the users can react in a reasonable amount of time. As long as the sensors are able to grab and transfer such data within two seconds or less, the software can be deemed as successful. The patient’s data must also be encrypted during the time of transfer and decrypted upon retrieval. This is to make such data legible to the user but illegible once inside the online database to prevent leaking sensitive information. In order to maintain this functionality, the mobile device must be constantly connected to the internet, whether through WiFi or through mobile internet.

### 5.2 Safety Requirements

Due to the system being most reliant on software based functionality, there are minimal safety requirements that need to be followed. In terms of the hardware, most of the sensors would be built into ambulance vehicle, encased within the dashboard. Most of the safeguards would already be in place to prevent any harm from usage. Safety precautions of different mobile devices would depend on other manufacturers that created those devices.

### 5.3 Security Requirement

The main security requirement of EmergensUI is the encryption of sensitive data being held in the online database. The software will implement encryption processes during the transfer of any data being sent towards the database. There will be a secondary security process that will be implemented to authorize certain users into the application to give access to certain individuals to certain sensitive medical information of patients. This authorization and verification process will make it so unrelated users will incapable of accessing sensitive health information of patients and contact information of medical employees. In the case of someone trying to use injection techniques to extract data from the database, a prepared statement within the program will allow the prevention of this scenario. To ensure that access is only given to specific individuals within medical facilities, a dedicated and trustworthy IT department is required to supply login information.

### 5.4 Software Quality Attributes

The EmergensUI should be able to run on any device platform that runs the Android OS, Lollipop or higher. This software should be able to adapt to any screen resolution in terms of usage. Screen resolution should not affect its usability. Labels and instructions within the application should be made clear as possible. This means that each feature should be easily comprehensible and easy to use upon viewing. The application should be relatively easy to maintain by the IT department of each of our clients and their users. It will provide a user-friendly experience that will bring ease and convenience of the communication feature between users. The application should robust enough to the point where it can handle multiple communicative routines at the same time by multiple users on the network. While handling communications, it should also be able to withstand large amounts of data storage to hold within its database. Maintenance will constantly be done to help maintain the application’s reusability and reliability, updates should be released monthly to reduce future bugs that may arise.

### 5.5 Business Rules

The main business rule for EmergensUI is to restrict access patient information to user classes of nurses and doctor roles within hospitals. This can be done through the main IT department of these facilities. The IT department can verify the role of these users and implement them into the system with new login information. The software will first verify the user and check the class of their role. It will then check if the patient they are looking for is within the database, if they are then it will process to verify and authorize if the user has access to these files; if they don’t however, it should show a cautionary symbol and alert to indicate that the file is private. However, if the patient doesn’t exist within the database, it’s the IT department’s job to implement the patient to the list along with basic information. Other specific health information would then be updated if doctor has access to their files. Usually paramedics are meant to take patients to their main hospital facility; however, due to the fact that there is a system in place to monitor patient vitals, the system would be able to navigate the paramedics to the nearest hospital to prevent the patient’s health from deteriorating further.

## 6. Other Requirements

As development continues on the EmergensUI project, there may be other database requirements, internalization requirements, legal requirements or other objectives and goals that may be added to the documentation. However, this section remains a placeholder until further features and requirements are announced.

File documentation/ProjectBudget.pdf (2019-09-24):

Product (Name) | Description | Model ID | Source (Supplier) | CAD$ Unit Cost | CAD$ Shipping | CAD$ Customs | Taxes | Subtotal

BerryGPS-IMU V3

Module with GPS(Ublox CAM-M8) & LSM9DS1 Sensors

Ozzmaker.com
http://tiny.cc/pigbdz | $ | 55.69 $ | 21.56 $ | - | $ | - | $ | 77.25

3x STM32Duino Blue Pill

Blue Pill w/ Arduino Boot
Loader | STMCS32F103C8T6

Amazon.ca
http://tiny.cc/dagbdz $ | 19.98 $ | - | $ | - | $ | 2.60 $ | 22.58

Adafruit 9-DOF Breakout

LSM9DS1 (Emergency Sensor)
if BerryGPS isn't compatible 3387 (LSM9DS1)

Adafruit.com
http://tiny.cc/0mgbdz $ | 14.95 $ | 22.05 $ | 1.94 $ | - | $ | 38.94

Ublox CAM-M8Q Sensor

Sole CAM-M8Q GPS Sensor if
BerryGPS isn't compatible | CAM-M8Q-0

U-Blox.com
http://tiny.cc/ctgbdz | $ | 33.14 $ | 51.70 $ | 6.54 $ | - | $ | 91.38

Parts Kit

Parts Kit already bought from
first year. | Humber College | $ | - | $ | - | $ | - | $ | - | $ | -
| Total Unit Cost | $ | 123.76
| Total Shipping Cost | $ | 95.31
| Total Customs | $ | 8.48
| Total Taxes | $ | 2.60
Budget for: | Kevin Lieng | Grand Total Cost | $ | 230.15

# Digital Dashboard - GPS w/ Compass

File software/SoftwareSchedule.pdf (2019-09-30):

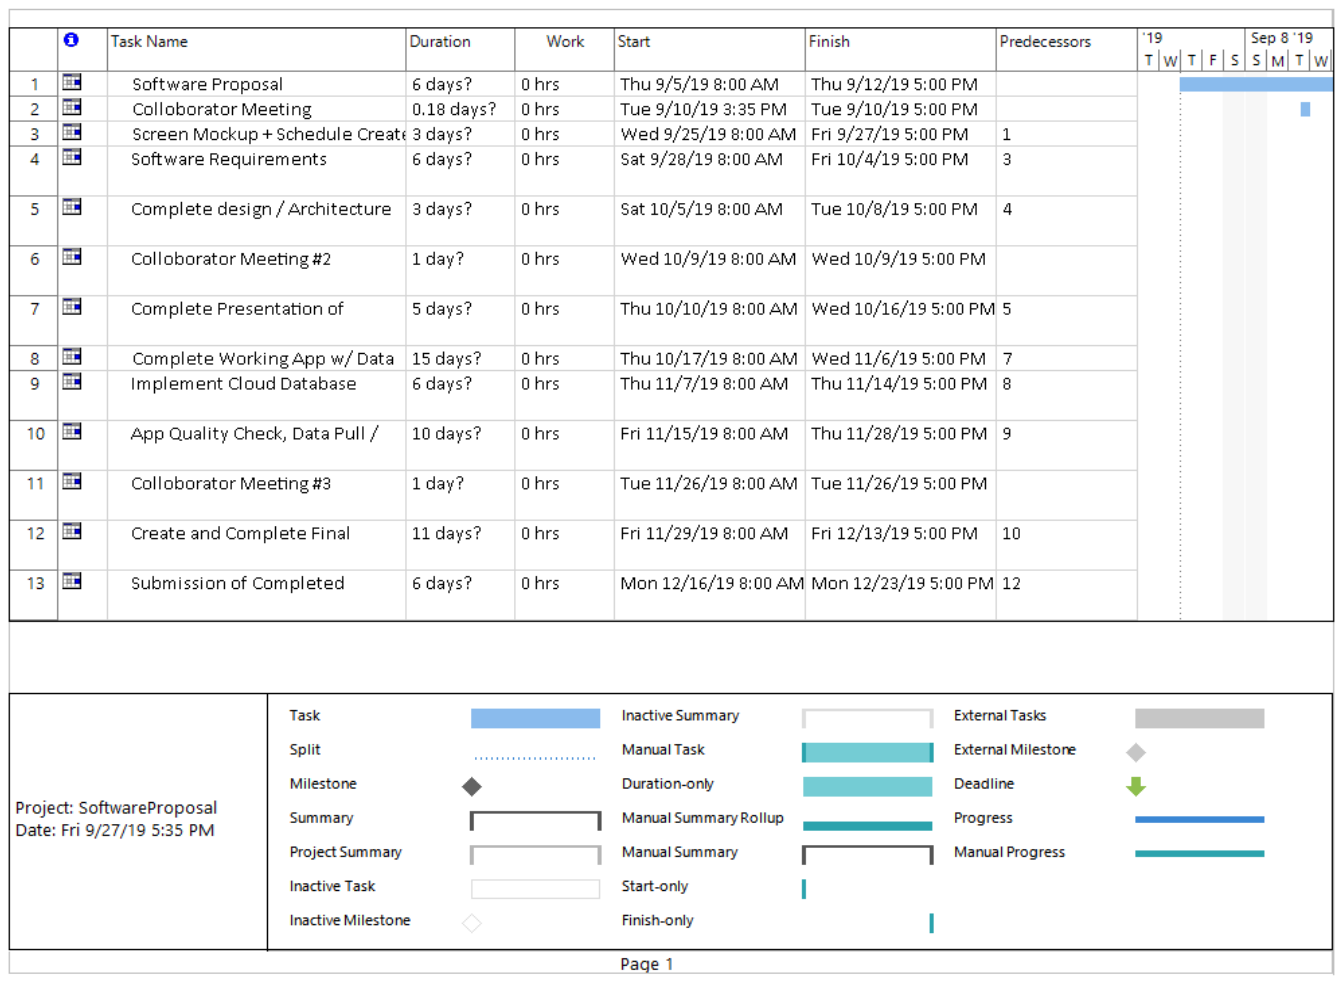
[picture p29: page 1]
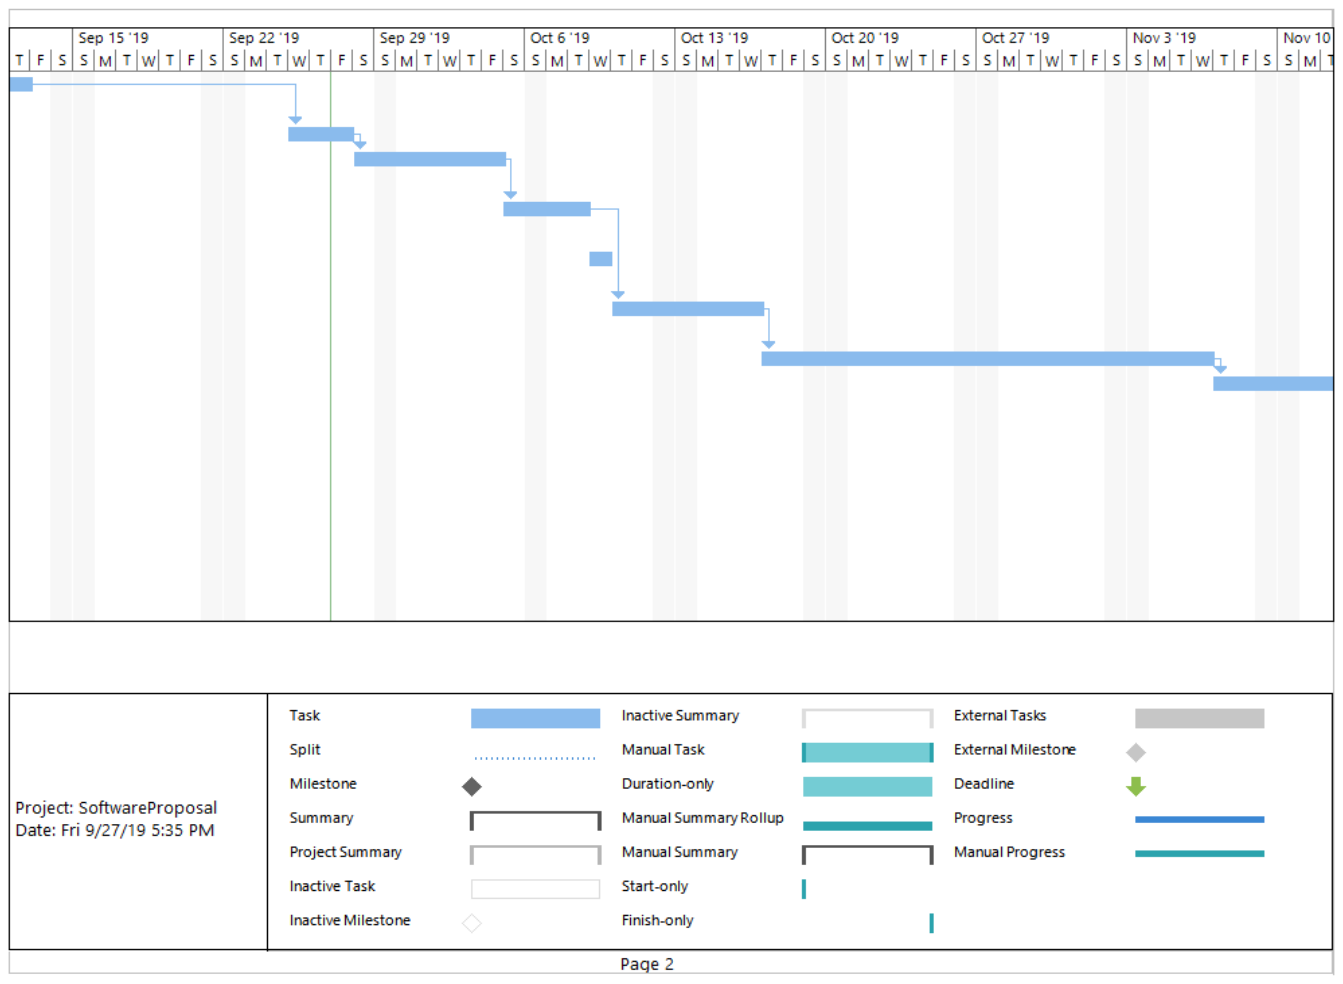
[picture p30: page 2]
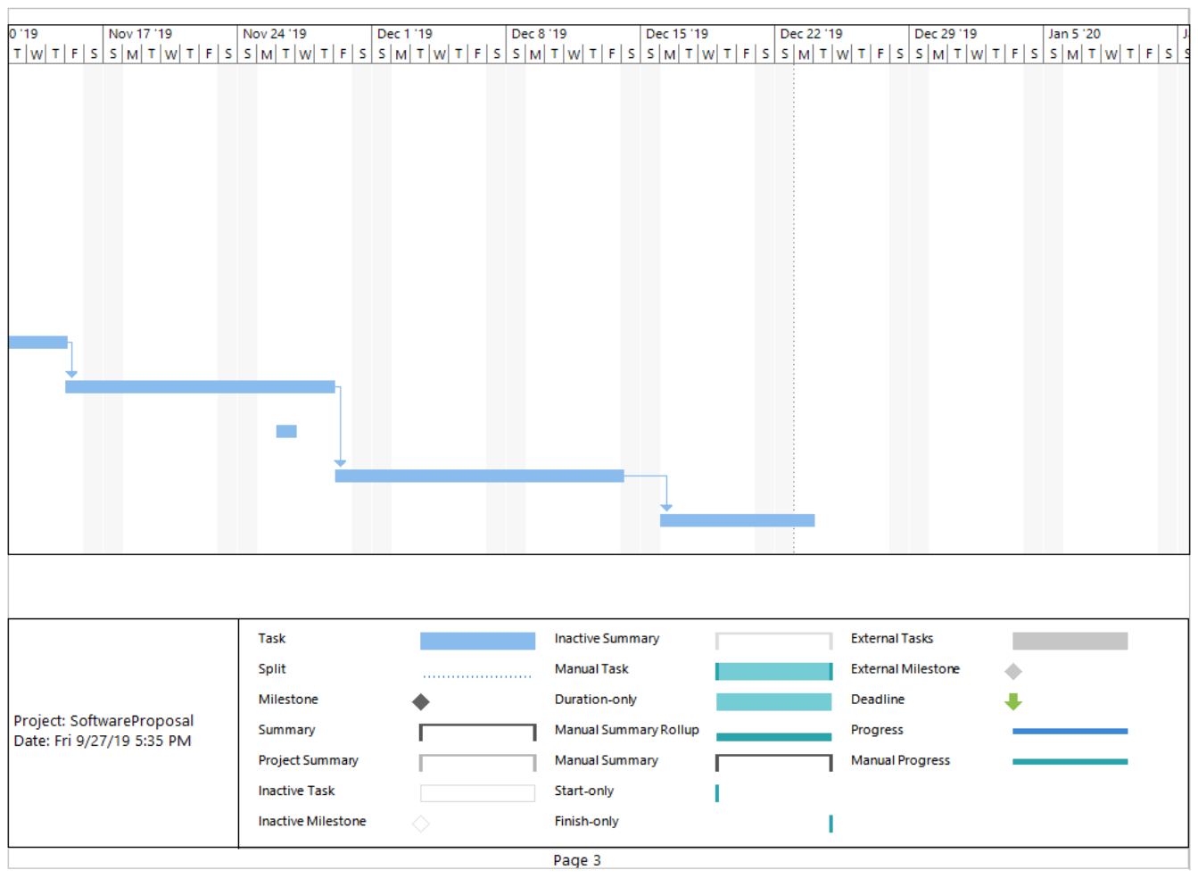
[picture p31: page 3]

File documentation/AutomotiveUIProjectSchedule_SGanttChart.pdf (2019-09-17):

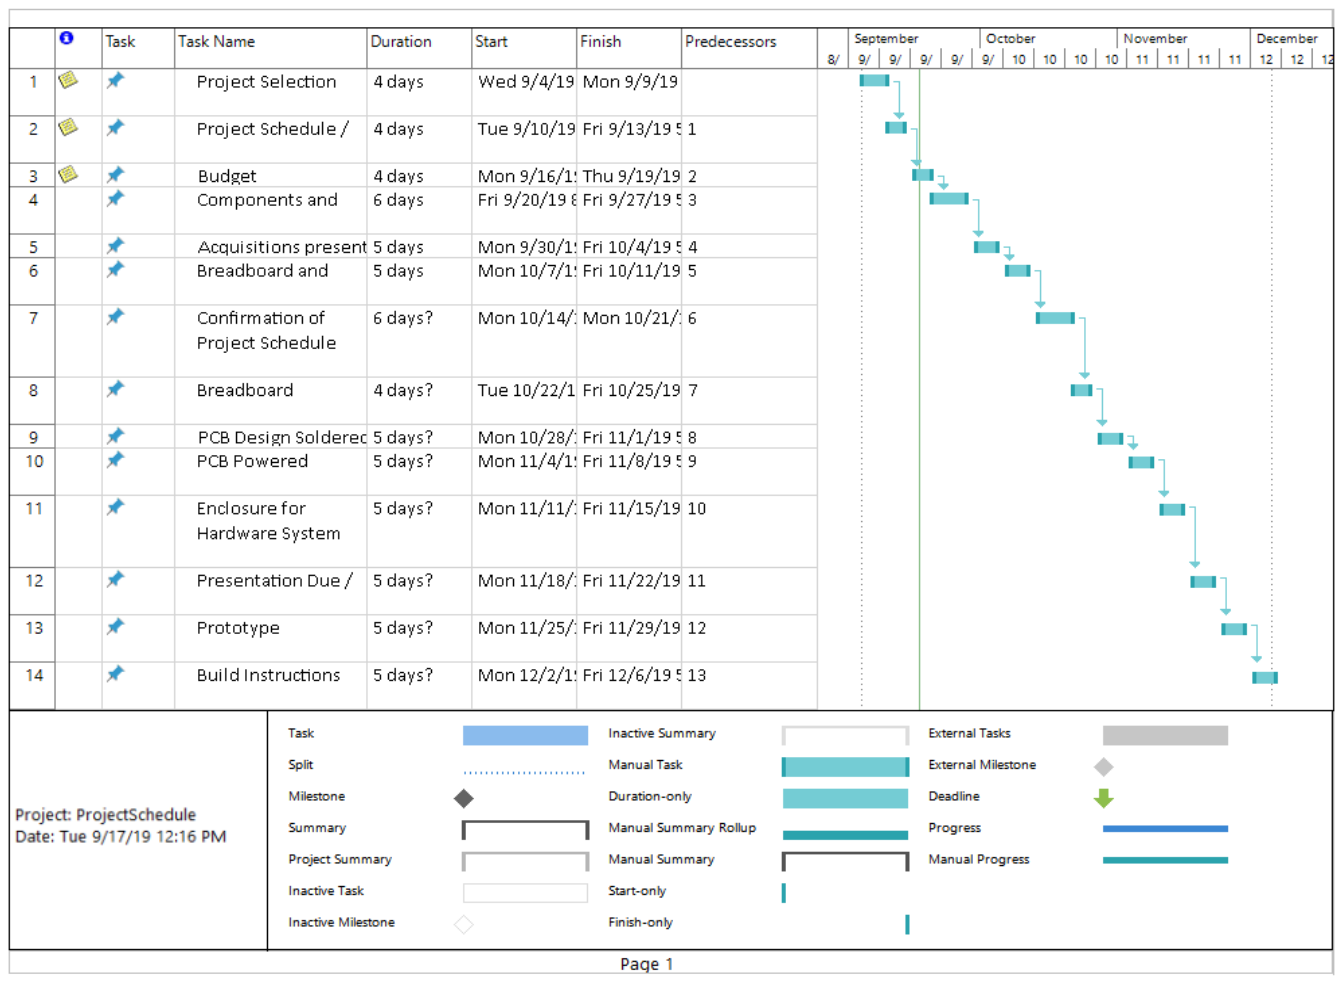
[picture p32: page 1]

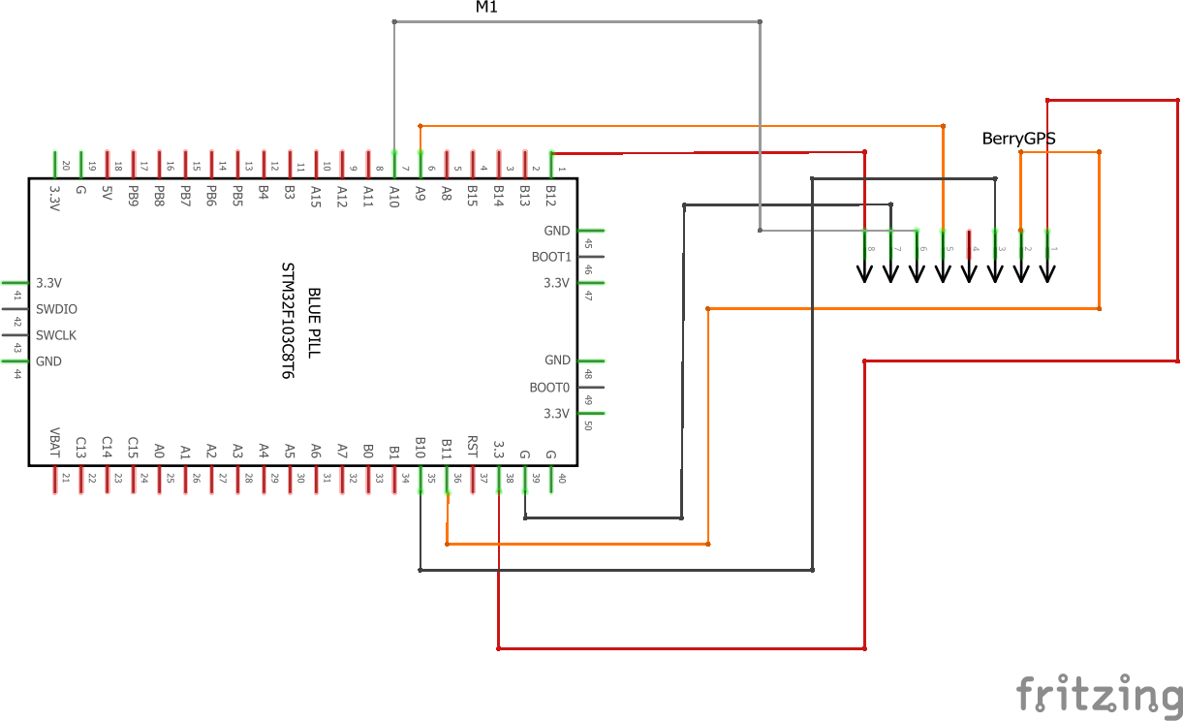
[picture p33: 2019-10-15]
electronics/PCB Socket Schematic Revised.png

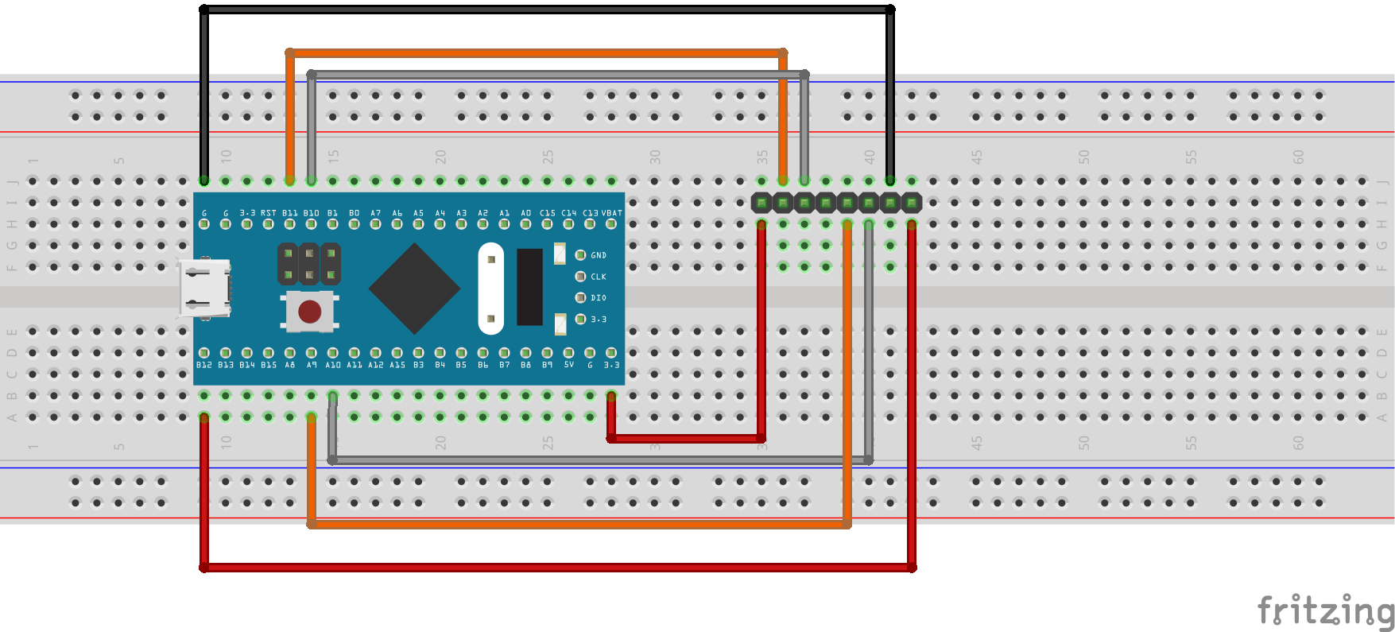
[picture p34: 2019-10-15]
electronics/PCB Socket Breadboard Revised.png

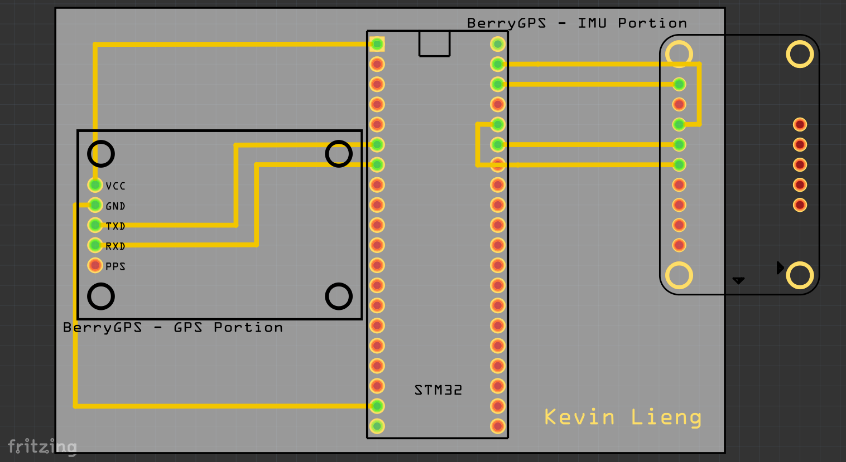
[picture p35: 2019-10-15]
electronics/PCB Board Plan.png

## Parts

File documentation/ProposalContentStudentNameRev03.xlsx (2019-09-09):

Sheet: DataEntry
Submission Date | 2019-09-10
Project Name | EmergensUI - Vehicle Dashboard (GPS portion)
Student Names | Kevin Lieng, Quyen Lu, and Seung Min Song
Project repository | https://github.com/kevin-lieng/emegensui-automotive-ui
SensorsEffectors choices | BerryGPS-IMU V3 or Adafruit Ultimate GPS with gpsd
The database will store | the locations that is captured through the GPS sensors in latitude and longitude.
The mobile device functionality will include | the ability to allow the communication between the dispatcher with paramedics and/or doctors and nurses to allow for quick response times and reduced panic. In terms of digital dashboard functionality, the dashboard should be able to display the basic information car information when driving. (Speedometer, tachometer, odometer, temperature gauges, navigational system).
I will be collaborating with the following company/department | Industrial Design mentor, Professor Dennis Kappen
My group in the winter semester will include | Quyen Lu and Seung Min Song.
50 word problem statement | In the current state, medical emergencies can be made more efficient. The communication between dispatchers, paramedics, and doctors are not in sync and can be improved to allow for quicker response and preparation times. If this can be solved, the chances for survival for patients can be increased if they can be attended to efficiently.
100 words of background | The project that we are currently working on is a concept that may be implemented into future ambulances to allow the paramedics to easier communicate between the dispatcher and doctors at the hospital. This can all be achieved through a more technological or digital dashboard within future ambulances. It would essentially still function normally as an ambulance with more up to date technology to decrease the time needed to transfer patient medical information in real time between dispatchers, paramedics, and doctors. This can either be done through the digital dashboard or through the mobile application.
Current product APA citation | Formosa, B. (2019, February 13). Collaboration at Humber College creates augmented reality for emergency vehicles. Retrieved from https://www.gh360.ca/?p=7393
Existing research IEEE paper APA citation | Akin, B., Choi, S., & Toliyat, H. A. (2012). DSP Applications in Electric and Hybrid Electric Vehicles [In the Spotlight]. IEEE Signal Processing Magazine, 29(3), 133–136. doi: 10.1109/MSP.2012.2185863
Brief description of planned purchases | I plan to purchase: a raspberry pi 3 kit, either the BerryGPS-IMU V3 sensors or the Adafruit Ultimate GPS with gpsd sensors.
Solution description | The digital dashboard and mobile application within this project would allow for a more up to date approach to send and retrieve a patient's medical information. Although just a concept, if fully implemented it would declutter the outdated technology that is within current ambulances and allow for more space and functionality within future ambulances. All in all, becoming a "smart" ambulance.

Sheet: DataBase
Submission Date | Project Name | Student Names | Project repository | SensorsEffectors choices | The database will store | The mobile device functionality will include | I will be collaborating with the following company/department | My group in the winter semester will include | 50 word problem statement | 100 words of background | Current product APA citation | Existing research IEEE paper APA citation | Brief description of planned purchases | Solution description
43718 | EmergensUI - Vehicle Dashboard (GPS portion) | Kevin Lieng, Quyen Lu, and Seung Min Song | https://github.com/kevin-lieng/emegensui-automotive-ui | BerryGPS-IMU V3 or Adafruit Ultimate GPS with gpsd | the locations that is captured through the GPS sensors in latitude and longitude. | the ability to allow the communication between the dispatcher with paramedics and/or doctors and nurses to allow for quick response times and reduced panic. In terms of digital dashboard functionality, the dashboard should be able to display the basic information car information when driving. (Speedometer, tachometer, odometer, temperature gauges, navigational system). | Industrial Design mentor, Professor Dennis Kappen | Quyen Lu and Seung Min Song. | In the current state, medical emergencies can be made more efficient. The communication between dispatchers, paramedics, and doctors are not in sync and can be improved to allow for quicker response and preparation times. If this can be solved, the chances for survival for patients can be increased if they can be attended to efficiently. | The project that we are currently working on is a concept that may be implemented into future ambulances to allow the paramedics to easier communicate between the dispatcher and doctors at the hospital. This can all be achieved through a more technological or digital dashboard within future ambulances. It would essentially still function normally as an ambulance with more up to date technology to decrease the time needed to transfer patient medical information in real time between dispatchers, paramedics, and doctors. This can either be done through the digital dashboard or through the mobile application. | Formosa, B. (2019, February 13). Collaboration at Humber College creates augmented reality for emergency vehicles. Retrieved from https://www.gh360.ca/?p=7393 | Akin, B., Choi, S., & Toliyat, H. A. (2012). DSP Applications in Electric and Hybrid Electric Vehicles [In the Spotlight]. IEEE Signal Processing Magazine, 29(3), 133–136. doi: 10.1109/MSP.2012.2185863 | I plan to purchase: a raspberry pi 3 kit, either the BerryGPS-IMU V3 sensors or the Adafruit Ultimate GPS with gpsd sensors. | The digital dashboard and mobile application within this project would allow for a more up to date approach to send and retrieve a patient's medical information. Although just a concept, if fully implemented it would declutter the outdated technology that is within current ambulances and allow for more space and functionality within future ambulances. All in all, becoming a "smart" ambulance.

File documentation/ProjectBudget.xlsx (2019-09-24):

Digital Dashboard - GPS w/ Compass
Product (Name) | Description | Model ID | Source (Supplier) | CAD$ Unit Cost | CAD$ Shipping | CAD$ Customs | Taxes | Subtotal
BerryGPS-IMU V3 | Module with GPS(Ublox CAM-M8) & LSM9DS1 Sensors |  | Ozzmaker.com http://tiny.cc/pigbdz | $55.69 | $21.56 | $0.00 | $0.00 | $77.25
3x STM32Duino Blue Pill | Blue Pill w/ Arduino Boot Loader | STMCS32F103C8T6 | Amazon.ca http://tiny.cc/dagbdz | $19.98 | $0.00 | $0.00 | $2.60 | $22.58
Adafruit 9-DOF Breakout | LSM9DS1 (Emergency Sensor) if BerryGPS isn't compatible | 3387 (LSM9DS1) | Adafruit.com http://tiny.cc/0mgbdz | $14.95 | $22.05 | $1.94 | $0.00 | $38.94
Ublox CAM-M8Q Sensor | Sole CAM-M8Q GPS Sensor if BerryGPS isn't compatible | CAM-M8Q-0 | U-Blox.com http://tiny.cc/ctgbdz | $33.14 | $51.70 | $6.54 | $0.00 | $91.38
Parts Kit | Parts Kit already bought from first year. |  | Humber College | $0.00 | $0.00 | $0.00 | $0.00 | $0.00
 |  |  | Total Unit Cost | $123.76
 |  |  | Total Shipping Cost | $95.31
 |  |  | Total Customs | $8.48
 |  |  | Total Taxes | $2.60
Budget for: | Kevin Lieng |  | Grand Total Cost | $230.15

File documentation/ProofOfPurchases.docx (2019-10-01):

Proof Of Purchases

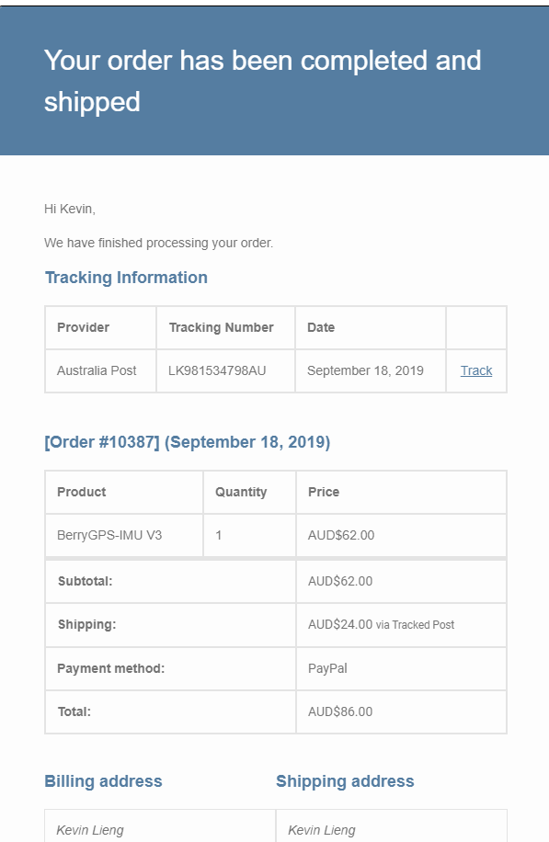
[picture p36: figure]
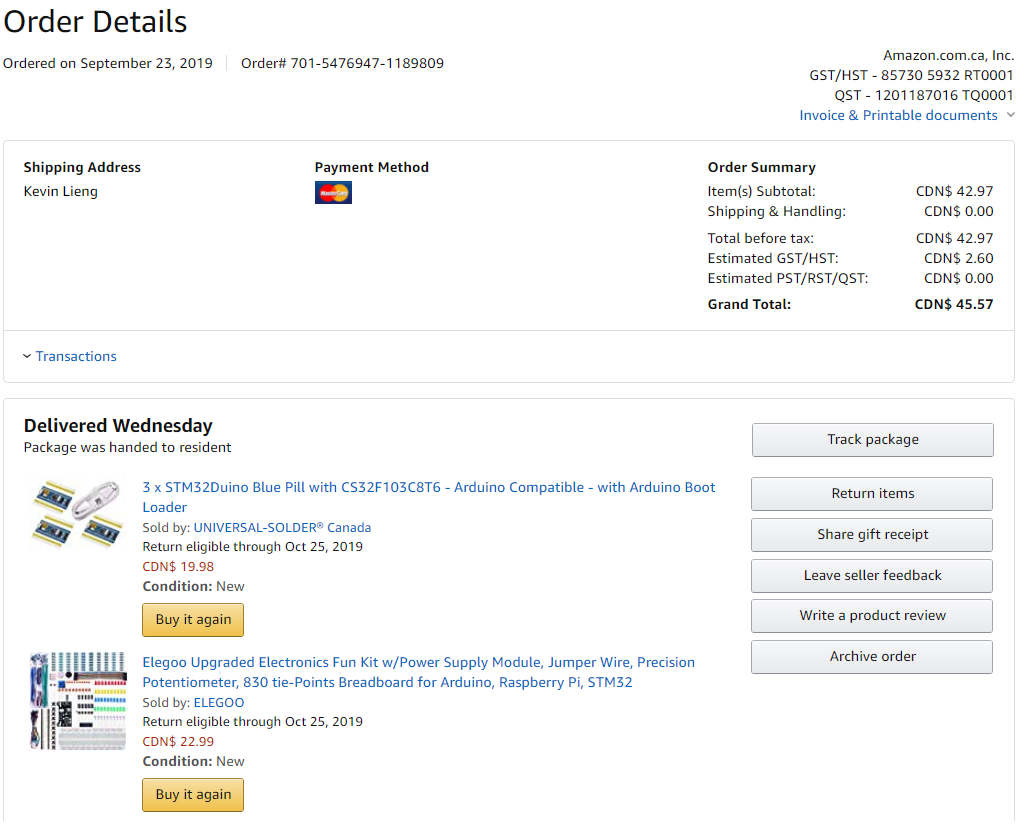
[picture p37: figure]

Kevin Lieng N00668906October 1, 2019

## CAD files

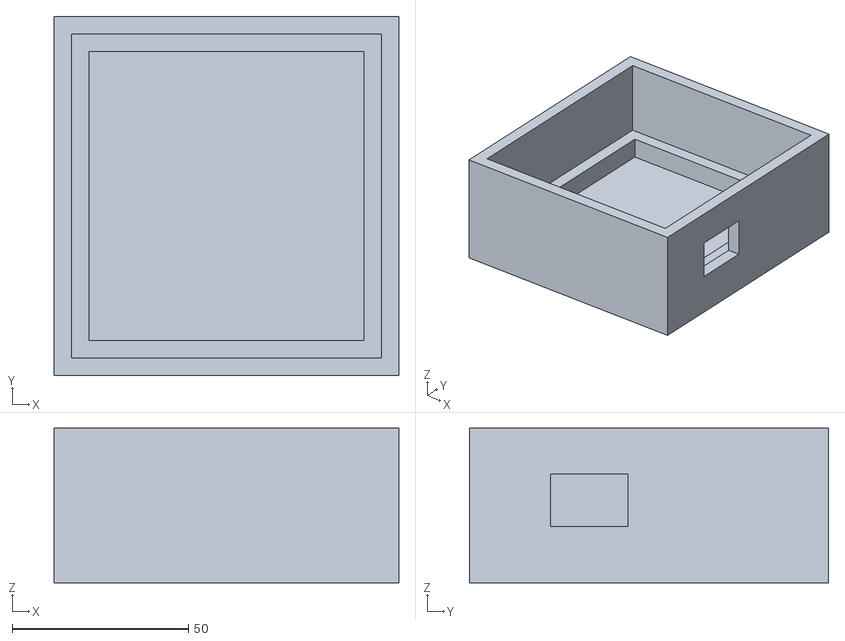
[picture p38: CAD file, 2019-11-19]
mechanical/PCBEnclosureFixed.stl
98.0 x 102.0 x 44.0

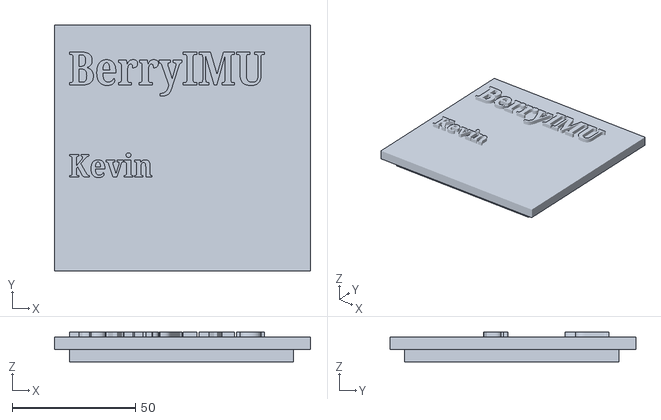
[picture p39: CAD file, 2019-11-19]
mechanical/PCBEnclosureLidFixed.stl
104.0 x 100.0 x 12.0

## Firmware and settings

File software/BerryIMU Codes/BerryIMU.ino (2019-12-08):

/*
  This program  reads the angles and heading from the accelerometer, gyroscope
   and compass on a BerryIMU connected to an Arduino.
  
    Both the BerryIMUv1 and BerryIMUv2 are supported.
    Feel free to do whatever you like with this code
    Distributed as-is; no warranty is given.
    http://ozzmaker.com/
*/

#include "IMU.h"

#define DT  0.02          // Loop time
#define AA  0.97         // complementary filter constant
#define G_GAIN 0.070    // [deg/s/LSB]

byte buff[6];
int accRaw[3];
int magRaw[3];
int gyrRaw[3];
float rate_gyr_y = 0.0;   // [deg/s]
float rate_gyr_x = 0.0;    // [deg/s]
float rate_gyr_z = 0.0;     // [deg/s]
float gyroXangle = 0.0;
float gyroYangle = 0.0;
float gyroZangle = 0.0;
float AccYangle = 0.0;
float AccXangle = 0.0;
float CFangleX = 0.0;
float CFangleY = 0.0;


unsigned long startTime;

void setup() {
         // join i2c bus (address optional for master)
  Serial.begin(115200);  // start serial for output

  detectIMU();
  enableIMU();


}

void loop() {
 startTime = millis();

  //Read the measurements from  sensors
  readACC(buff);
  accRaw[0] = (int)(buff[0] | (buff[1] << 8));   
  accRaw[1] = (int)(buff[2] | (buff[3] << 8));
  accRaw[2] = (int)(buff[4] | (buff[5] << 8));

  readMAG(buff);
  magRaw[0] = (int)(buff[0] | (buff[1] << 8));   
  magRaw[1] = (int)(buff[2] | (buff[3] << 8));
  magRaw[2] = (int)(buff[4] | (buff[5] << 8));


  readGYR(buff);
  gyrRaw[0] = (int)(buff[0] | (buff[1] << 8));   
  gyrRaw[1] = (int)(buff[2] | (buff[3] << 8));
  gyrRaw[2] = (int)(buff[4] | (buff[5] << 8));

  
  //Convert Gyro raw to degrees per second
  rate_gyr_x = (float) gyrRaw[0] * G_GAIN;
  rate_gyr_y = (float) gyrRaw[1]  * G_GAIN;
  rate_gyr_z = (float) gyrRaw[2]  * G_GAIN;

  //Calculate the angles from the gyro
  gyroXangle+=rate_gyr_x*DT;
  gyroYangle+=rate_gyr_y*DT;
  gyroZangle+=rate_gyr_z*DT;

  //Convert Accelerometer values to degrees
  AccXangle = (float) (atan2(accRaw[1],accRaw[2])+M_PI)*RAD_TO_DEG;
  AccYangle = (float) (atan2(accRaw[2],accRaw[0])+M_PI)*RAD_TO_DEG;


  //If IMU is up the correct way, use these lines
        AccXangle -= (float)180.0;
  if (AccYangle > 90)
          AccYangle -= (float)270;
  else
    AccYangle += (float)90;


  //Complementary filter used to combine the accelerometer and gyro values.
  CFangleX=AA*(CFangleX+rate_gyr_x*DT) +(1 - AA) * AccXangle;
  CFangleY=AA*(CFangleY+rate_gyr_y*DT) +(1 - AA) * AccYangle;


  //Compute heading  
  float heading = 180 * atan2(magRaw[1],magRaw[0])/M_PI;
  
  //Convert heading to 0 - 360
  if(heading < 0)
      heading += 360;
            
  Serial.print("#AccX\t");
  Serial.print(AccXangle);
  Serial.print("\t###  AccY  ");
  Serial.print(AccYangle);
  
  Serial.print("  ###  GyrX\t");
  Serial.print(gyroXangle);
  Serial.print("  ###  GyrY  \t");
  Serial.print(gyroYangle);
  Serial.print("   ###  GyrZ\t");
  Serial.print(gyroZangle);
  Serial.print("     ######    CFangleX\t");
  Serial.print(CFangleX);
  Serial.print("   ######  CFangleY   \t");
  Serial.print(CFangleY);
  Serial.print("   ######  heading   \t");
  Serial.print(heading); 
  Serial.print("    --Loop Time--\t");

  //Each loop should be at least 20ms.
  while(millis() - startTime < (DT*1000))
        {
            delay(1);
        }
  Serial.println( millis()- startTime);
 


}

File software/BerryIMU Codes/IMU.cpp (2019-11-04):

/*
  This program  reads the angles and heading from the accelerometer, gyroscope
   and compass on a BerryIMU connected to an Arduino.
  
    Both the BerryIMUv1 and BerryIMUv2 are supported.
    Feel free to do whatever you like with this code
    Distributed as-is; no warranty is given.
    http://ozzmaker.com/
*/


#include <Arduino.h>
#include <Wire.h>
#include "LSM9DS0.h"
#include "LSM9DS1.h"


int LSM9DS0 = 0;
int LSM9DS1 = 0;



void writeTo(int device, byte address, byte val) {
   Wire.beginTransmission(device); //start transmission to device 
   Wire.write(address);        // send register address
   Wire.write(val);        // send value to write
   Wire.endTransmission(); //end transmission
}
void readFrom(int device, byte address, int num, byte buff[]) {
  Wire.beginTransmission(device); //start transmission to device 
  Wire.write(address);        //sends address to read from
  Wire.endTransmission(); //end transmission
  
  Wire.beginTransmission(device); //start transmission to device (initiate again)
  Wire.requestFrom(device, num);    // request 6 bytes from device
  
  int i = 0;
  while(Wire.available())    //device may send less than requested (abnormal)
  { 
    buff[i] = Wire.read(); // receive a byte
    i++;
  }
  Wire.endTransmission(); //end transmission
}

void detectIMU(){
  Wire.begin(); 
  byte LSM9DS0_WHO_AM_I_G_response;
  byte LSM9DS0_WHO_AM_I_XM_response;
  byte LSM9DS1_WHO_M_response;
  byte LSM9DS1_WHO_XG_response;

  
  byte WHOresponse[2];

  //Detect if BerryIMUv1 (Which uses a LSM9DS0) is connected
  readFrom(LSM9DS0_GYR_ADDRESS, LSM9DS0_WHO_AM_I_G,1,WHOresponse);
  LSM9DS0_WHO_AM_I_G_response = WHOresponse[0];
  
  readFrom(LSM9DS0_ACC_ADDRESS, LSM9DS0_WHO_AM_I_XM,1,WHOresponse);
  LSM9DS0_WHO_AM_I_XM_response = WHOresponse[0];

  if (LSM9DS0_WHO_AM_I_G_response == 0xD4 && LSM9DS0_WHO_AM_I_XM_response == 0x49){
    Serial.println("\n\n   LSM9DS0 found \n\n");
    LSM9DS0 = 1;
  }

  
  //Detect if BerryIMUv2 (Which uses a LSM9DS1) is connected
  readFrom(LSM9DS1_MAG_ADDRESS, LSM9DS1_WHO_AM_I_M,1,WHOresponse);
  LSM9DS1_WHO_M_response = WHOresponse[0];
  
  readFrom(LSM9DS1_GYR_ADDRESS, LSM9DS1_WHO_AM_I_XG,1,WHOresponse);
  LSM9DS1_WHO_XG_response = WHOresponse[0];

  if (LSM9DS1_WHO_XG_response == 0x68 && LSM9DS1_WHO_M_response == 0x3D){
    Serial.println("\n\n   LSM9DS1 found \n\n");
    LSM9DS1 = 1;
  }
  
    
  delay(1000);
  
  
  
  


  }


void enableIMU(){


if (LSM9DS0){//For BerryIMUv1
  //Enable accelerometer
  writeTo(LSM9DS0_ACC_ADDRESS,LSM9DS0_CTRL_REG1_XM, 0b01100111); //  z,y,x axis enabled, continuos update,  100Hz data rate
  writeTo(LSM9DS0_ACC_ADDRESS,LSM9DS0_CTRL_REG2_XM, 0b00100000); // +/- 16G full scale

  //Enable the magnetometer
  writeTo(LSM9DS0_MAG_ADDRESS,LSM9DS0_CTRL_REG5_XM, 0b11110000);   // Temp enable, M data rate = 50Hz
  writeTo(LSM9DS0_MAG_ADDRESS,LSM9DS0_CTRL_REG6_XM, 0b01100000);   // +/-12gauss
  writeTo(LSM9DS0_MAG_ADDRESS,LSM9DS0_CTRL_REG7_XM, 0b00000000);   // Continuous-conversion mode

  // Enable Gyro
  writeTo(LSM9DS0_GYR_ADDRESS, LSM9DS0_CTRL_REG1_G, 0b00001111); // Normal power mode, all axes enabled
  writeTo(LSM9DS0_GYR_ADDRESS, LSM9DS0_CTRL_REG4_G, 0b00110000); // Continuos update, 2000 dps full scale
}
else if(LSM9DS1){//For BerryIMUv2  
      // Enable the gyroscope
    writeTo(LSM9DS1_GYR_ADDRESS,LSM9DS1_CTRL_REG4,0b00111000);      // z, y, x axis enabled for gyro
    writeTo(LSM9DS1_GYR_ADDRESS,LSM9DS1_CTRL_REG1_G,0b10111000);    // Gyro ODR = 476Hz, 2000 dps
    writeTo(LSM9DS1_GYR_ADDRESS,LSM9DS1_ORIENT_CFG_G,0b10111000);   // Swap orientation 

    // Enable the accelerometer
    writeTo(LSM9DS1_ACC_ADDRESS,LSM9DS1_CTRL_REG5_XL,0b00111000);   // z, y, x axis enabled for accelerometer
    writeTo(LSM9DS1_ACC_ADDRESS,LSM9DS1_CTRL_REG6_XL,0b00101000);   // +/- 16g

    //Enable the magnetometer
    writeTo(LSM9DS1_MAG_ADDRESS,LSM9DS1_CTRL_REG1_M, 0b10011100);   // Temp compensation enabled,Low power mode mode,80Hz ODR
    writeTo(LSM9DS1_MAG_ADDRESS,LSM9DS1_CTRL_REG2_M, 0b01000000);   // +/-12gauss
    writeTo(LSM9DS1_MAG_ADDRESS,LSM9DS1_CTRL_REG3_M, 0b00000000);   // continuos update
    writeTo(LSM9DS1_MAG_ADDRESS,LSM9DS1_CTRL_REG4_M, 0b00000000);   // lower power mode for Z axis
    
}
}

void readACC(byte buff[]){
  if (LSM9DS0)//For BerryIMUv1
    readFrom(LSM9DS0_ACC_ADDRESS, 0x80 | LSM9DS0_OUT_X_L_A, 6, buff);
  
  else if(LSM9DS1)//For BerryIMUv2  
    readFrom(LSM9DS1_ACC_ADDRESS, 0x80 | LSM9DS1_OUT_X_L_XL, 6, buff);
} 
 
void readMAG(byte buff[]){
  if (LSM9DS0)//For BerryIMUv1
    readFrom(LSM9DS0_MAG_ADDRESS, 0x80 | LSM9DS0_OUT_X_L_M, 6, buff);
  else if(LSM9DS1)//For BerryIMUv2  
    readFrom(LSM9DS1_MAG_ADDRESS, 0x80 | LSM9DS1_OUT_X_L_M, 6, buff);
  
}

void readGYR(byte buff[]){
  if (LSM9DS0)//For BerryIMUv1
  readFrom(LSM9DS0_GYR_ADDRESS, 0x80 | LSM9DS0_OUT_X_L_G, 6, buff);
  else if(LSM9DS1)//For BerryIMUv2 
  readFrom(LSM9DS1_GYR_ADDRESS, 0x80 | LSM9DS1_OUT_X_L_G, 6, buff);
}

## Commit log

2019-10-15 Create BerryGPS Fritzing Schematic + PCB.fzz
    [BerryGPS Fritzing Schematic + PCB.fzz]
2019-10-15 Create PCB Board Plan.png
2019-10-15 Create PCB Breadboard Design.png
2019-10-15 Create PCB Schematic.png
2019-10-15 Update PCB Schematic.png
2019-10-15 Update PCB Breadboard Design.png
2019-10-15 Update BerryGPS Fritzing Schematic + PCB.fzz
    [BerryGPS Fritzing Schematic + PCB.fzz]
2019-10-15 Create PCB Board Plan - Revised.png
2019-10-15 Create PCB Socket Breadboard Revised.png
2019-10-15 Create PCB Socket Schematic Revised.png
2019-11-12 Create Feather +BerryIMU Remake PCB.fzz
    [Feather +BerryIMU Remake PCB.fzz]
2019-12-08 Create PCB Gerber.rar
